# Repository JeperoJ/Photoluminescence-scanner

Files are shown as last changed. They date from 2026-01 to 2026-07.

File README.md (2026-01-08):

## Photoluminescence Scanner

Fork of: https://github.com/caee/Photoluminescence-scanner/
For more information about the project please visit the original repository.
Carl Emil Elling & Jeppe Elias Ekberg Jensen, 2025

<!--Thesis Project `Development of a diagnostic imaging system for field inspection solar photovoltaic PV plants` in collaboration with DTU Electro.

Carl Emil Elling, 2025

System functionality is demonstrated in this video: https://youtu.be/fIywvakTZRA

Example results found in the `Example Scans - Videos and images` folder

For access to thesis, find on DTU internal document query FindIT or contact directly at carlemilelling@hotmail.com -->

### Project Structure

- **Software:** Located in the `Software` folder. This folder contains the project software and calibration files. Note that the `.raw` calibration files are stored using Git LFS and are subject to a monthly bandwidth limit (1GB). These files are only needed for recalibration.
- **Mechanical Data:** Located in the `Mechanical` folder. This folder includes `.STL` files for all 3D printed components of the system, as well as `.step` files for the entire system assembly for reference.
- **PCB Data:** Located in the `PCB` folder. This folder contains data for the custom PCBs used for driving the IR LEDs.
- **Marlin-2.1.2.5-PLRobot:** This folder contains a custom fork of the open-source Marlin 3D printer software. Modified to the dimensions and setup of the PL Robot Scanner implemented in the project.

### Setup Instructions

1. **Download the FLI API:** Please download the proprietary First Light Imaging (FLI) API from their [website](https://andor.oxinst.com/downloads/view/first-light-imaging-sdk-installer) (user login required).
2. **Add FLI API to Work Folder:** Add the downloaded FLI API to the work folder to use the main script `PLRobot.py`.
3. Connect gantry and FLI C-RED 3 camera according to the thesis instructions.
4. Run `PLRobot.py`. Output images will be in the `Images`folder
(OPTIONAL) 5. If necessary, `Marlin-2.1.2.5-PLRobot`firmware can be updated or flashed with PlatformIO and and the `platformio.ino` file in the custom Marlin folder.

### License

This project is licensed under ????

The `Marlin-2.1.2.5-PLRobot` branch is a custom version of the Marlin 3D printer software specifically for this project. It is licensed under the [GPL license](Marlin-2.1.2.5-PLRobot/LICENSE), requiring open access to modifications ▋

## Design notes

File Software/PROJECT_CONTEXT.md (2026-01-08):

# PROJECT_CONTEXT.md

## AI Assistant Context File

### Project Overview
**System Name**: Photoluminescence (PL) Scanner for Solar Panel Inspection  
**Main Entry Point**: `PLRobot.py`  
**Repository**: https://github.com/JeperoJ/Photoluminescence-scanner  
**Working Directory**: `C:\Users\carle\Documents\GitHub\Photoluminescence-scanner\Software\`

This system performs automated scanning and imaging of photovoltaic (PV) panels using synchronized camera and gantry motion systems to detect defects through photoluminescence and electroluminescence imaging.

---

## System Architecture

### Hardware Components

#### 1. Camera System - FLI InGaAs (C-RED3)
- **Resolution**: 640×512 pixels
- **Frame Rate**: Configurable (default: 50 FPS)
- **Exposure**: Configurable (default: 1ms, variable `tintVal`)
- **Sensor Type**: InGaAs (Indium Gallium Arsenide) - Near-infrared sensitive
- **Calibration Features**:
  - Bad pixel correction
  - NUC (Non-Uniformity Correction) bias calibration
  - Adaptive bias (C-RED3 specific)
  - Anti-blooming (prevents pixel saturation bleed)
  - Auto-clip (dynamic range adjustment)

#### 2. Gantry System - Parallel X-Y Motion Control
- **Max Travel Distance**: ~2500mm total
  - `offsetBegin`: 500mm (from end stops to effective start)
  - `offsetEnd`: 100mm (from effective end to max travel)
  - **Effective Travel**: ~1900-2000mm
- **Speed**: Configurable (default: 5000 mm/min)
- **Communication**: Serial via GCode protocol
- **Dual-Axis**: Parallel X-Y synchronization with drift compensation
- **Drift Compensation**: 0.2448 mm/step (empirically determined)
  - Corrects for X and Y axes traveling different distances while ending simultaneously
  - Critical for stitching alignment

---

## Software Architecture

### Module Structure
```
Software/
??? PLRobot.py              # Main orchestration script
??? FLI_API/                # Camera SDK wrapper
?   ??? FliSdk_V2           # FLI SDK v2 interface
??? Acquisition/            # Image acquisition logic
?   ??? imageAcquisition    # Camera init, capture, bias correction
??? Stitching/              # Image stitching algorithms
?   ??? stitchImages        # PL/Geo/Multi/Continuous stitching
??? lib/                    # Core utilities
?   ??? ProcessInGaAs       # InGaAs sensor image processing
?   ??? imageAcquisition    # Camera initialization and capture
?   ??? gCodeHandler        # GCode serial communication
?   ??? stitchImages        # Stitching implementations
??? Images/                 # Output directory for scans
??? Calibration/            # Undistortion matrices (K, P, DIM)
??? PROJECT_CONTEXT.md      # This file
```

### Key Dependencies
- **OpenCV** (`cv2`) - Image processing and display
- **tifffile** - TIFF file I/O
- **NumPy** - Matrix operations (implied, for calibration matrices)
- **FLI_API** - Vendor SDK for camera control
- **pyserial** (implied) - Serial communication for GCode

---

## Workflow Pipeline

### Phase 1: Calibration
1. **Undistortion Calibration**
   - Load existing calibration matrices: `K` (camera matrix), `P` (projection matrix), `DIM` (dimensions)
   - Default path: `./Calibration/`
   - Matrices stored as NumPy `.npy` files

2. **Camera Initialization**
   ```python
   context = FliSdk_V2.Init()
   initCamera(context, frameRate, tintVal)
   ```
   - User prompted for bias correction method (NUC vs Adaptive)
   - Anti-blooming and auto-clip enabled
   - Optional: Live preview via `justShowImage()`

3. **Gantry Calibration**
   - Check end stops (M119 GCode)
   - Auto-recovery if triggered (move 30mm away)
   - Auto-home sequence
   - Wait for completion (M400)

### Phase 2: Scanning

#### Mode 1 - Multi-Step Scan (3-position stepped acquisition)
```python
scan(gcode_handler, context, savePath, frameRate, speed=5000, nsteps=3)
```
- **Process**:
  1. Divide travel distance by `nsteps` (default: 3)
  2. Create position array: `[[0,0], [dist,dist], [2*dist,2*dist], [3*dist,3*dist]]`
  3. For each position:
     - Move camera to X position
     - Move light bar along Y while capturing images
     - Save as `scan_{step}.tiff`
- **Image Calculation**: `nImages = int(dist_travel / (speed/60) * frameRate)`
- **Buffer**: `nImages + 5` (may be too small, noted in comments)

#### Mode 2 - Continuous Scan (single-pass continuous capture)
```python
scanContinuous(gcode_handler, context, savePath, frameRate, speed=5000)
```
- **Process**:
  1. Move to start position (200, 0)
  2. Simultaneously move both axes to (2100, 2000) while capturing
  3. Save as `scan_cont_{timestamp}.tiff`
- **Buffer**: `nImages + 400` (larger buffer for continuous capture)
- **Timestamp Format**: `YYYY-MM-DD_HH-MM`

#### Mode 3 - Electroluminescence (EL) Scan (incomplete)
```python
scanEL(gcode_handler, context, savePath, frameRate, speed=5000)
```
- **Status**: Partial implementation
- **Difference**: Only moves camera axis (1800mm travel)
- **Output**: `scan_EL_cont_{timestamp}.tiff`

### Phase 3: Processing & Stitching

#### Image Loading
- **RAW files**: `ProcessInGaAs.load_raw_image(path, 640, 512)`
- **TIFF files**: `tifffile.imread()` ? `int16_2_uint16()` conversion

#### Stitching Methods
1. **roughStitchPL** - Photoluminescence-based stitching
2. **roughStitchGeo** - Geometry-based stitching (uses speed, nsteps, FPS)
3. **multiStitch** - Combines multiple `GeoPL_stitched.png` images
4. **roughStitchCont** - Continuous scan stitching (uses drift compensation)

#### Output Files
- Individual stitches: `*_stitched.png`
- Geo+PL stitches: `*_GeoPL_stitched.png`
- Final continuous: `stitched_image_cont.png`

---

## Critical Technical Details

### Scan Calculations
```python
# Number of images to capture
nImages = int(dist_travel / (speed/60) * frameRate)

# Example: 2000mm travel, 5000 mm/min speed, 50 FPS
# nImages = int(2000 / (5000/60) * 50) = int(2000 / 83.33 * 50) = 1200 images
```

### Buffer Sizing
- **Multi-step**: `nImages + 5` ?? May cause buffer overflow
- **Continuous**: `nImages + 400` (safer margin)
- **EL scan**: `nImages + 400`

### Drift Compensation
- **Value**: 0.2448 mm/step
- **Cause**: X and Y axes travel different actual distances but complete simultaneously
- **Detection**: Stitched images align at start but misalign at end
- **Application**: Used in `roughStitchCont()` function

### File Naming Conventions
| Scan Type | Filename Pattern | Extension |
|---|---|---|
| Multi-step | `scan_{step_number}` | `.tiff` |
| Continuous PL | `scan_cont_{timestamp}` | `.tiff` |
| Continuous EL | `scan_EL_cont_{timestamp}` | `.tiff` |
| Stitched output | `*_stitched` | `.png` |
| Geo+PL stitched | `*_GeoPL_stitched` | `.png` |

---

## Known Issues & Limitations

### Active Issues
1. **Buffer Sizing**: Multi-step scan buffer (`nImages + 5`) may be too small
2. **Error Handling**: Bare `except:` clauses catch all exceptions
3. **String Comparison**: `if scantype==1:` should be `if scantype=="1":` (line 330)
4. **Incomplete Feature**: `scanEL()` function partially implemented
5. **Calibration Path**: Alternative calibration workflow commented out

### Design Decisions
- **Interactive Prompts**: All operations require user confirmation (blocking I/O)
- **Sequential Processing**: No parallel/async operations
- **File Discovery**: Latest scan uses `os.path.getctime()` (creation time)

### Safety Features
- End-stop checking with auto-recovery (max 2 attempts per axis)
- Emergency stop capability (`x` key during prompts)
- Gantry position verification before critical operations

---

## Configuration Parameters

### Default Values (in `main()`)
```python
speed = 5000              # Gantry speed (mm/min)
frameRate = 50            # Camera frame rate (FPS)
tintVal = 1               # Exposure time (ms)
nsteps = 3                # Number of steps for multi-step scan
drift = 0.2448            # Drift compensation (mm/step)
offsetBegin = 500         # Start offset (mm)
offsetEnd = 100           # End offset (mm)
dist_travel = 2000        # Effective travel distance (mm)
```

### Camera Dimensions
```python
width = 640               # Sensor width (pixels)
height = 512              # Sensor height (pixels)
```

---

## GCode Commands Used

| Command | Purpose |
|---|---|
| M120 | Enable end stops |
| M119 | Check end stop status |
| M400 | Wait for all moves to complete |
| M114 | Get current position |
| G0 X## Y## | Rapid positioning move |

---

## Future Enhancements (TODOs in code)

1. **Flat Correction**: Non-uniformity response correction (currently commented out)
   - Reference: HDR mode documentation (Andor)
2. **GUI Implementation**: `GUI()` function placeholder at end of `main()`
3. **Complete EL Scanning**: Finish `scanEL()` implementation
4. **Improved Calibration Workflow**: Re-enable checkerboard calibration path

---

## Troubleshooting Guide

### Stitching Alignment Issues
- **Symptom**: Images align at start but not at end
- **Solution**: Adjust `drift` parameter in `main()`

### Buffer Overflow
- **Symptom**: Missing frames at end of acquisition
- **Solution**: Increase buffer margin in `scan()` from `+5` to `+400`

### End Stop Triggered
- **Symptom**: "End stop triggered" during calibration
- **Solution**: Automatic recovery moves 30mm away (max 2 attempts)

### Camera Not Found
- **Symptom**: `FliSdk_V2.Init()` fails
- **Solution**: Check USB connection, ensure FLI drivers installed

---

## Version Information
- **Last Updated**: Initial context file creation
- **Python Version**: 3.x (inferred from syntax)
- **FLI SDK**: V2

---

## Notes for AI Assistants

### When Modifying This Code:
1. ? Maintain existing variable names (`gCode_handler` vs `gcode_handler`)
2. ? Preserve GCode command sequences (order matters)
3. ? Keep drift compensation calculations intact
4. ? Maintain buffer size calculations (critical for data integrity)
5. ?? Test any changes to timing-sensitive operations (gantry + camera sync)

### Common User Requests:
- Adding new scan patterns ? Reference `scan()` and `scanContinuous()` structure
- Adjusting image quality ? Modify `frameRate`, `tintVal`, or calibration steps
- Changing travel distances ? Update `offsetBegin`, `offsetEnd`, `dist_travel`
- Adding new stitching methods ? See `stitchImages` module

### Code Style Notes:
- Minimal inline comments (only for complex logic)
- User prompts are verbose and instructional
- Error handling uses simple print + sys.exit() pattern
- Function parameters use descriptive names with units in comments

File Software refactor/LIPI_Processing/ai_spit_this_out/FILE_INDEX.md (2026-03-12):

# Modulated Peak Width Detection - File Index

## Quick Navigation

### 🚀 **START HERE**
- **00_PACKAGE_SUMMARY.md** - Overview of the solution
- **QUICKSTART.py** - Copy-paste examples (3 lines to get started!)

### 📚 **Documentation**
- **MODULATED_PEAK_DETECTION_README.md** - Full technical documentation
  - How it works (Hilbert Transform)
  - Parameter tuning guide
  - Comparison with other methods
  - Troubleshooting

### 💻 **Code Files**

#### Core Library
- **modulated_peak_detector.py** - Main detection engine
  - `detect_modulated_peak_width()` - Detect single peak
  - `detect_multiple_modulated_peaks()` - Find multiple peaks
  - Helper functions for envelope extraction

#### Specialized Tools
- **photoluminescence_analysis.py** - High-level analysis for your use case
  - `analyze_scan_line()` - Detailed line profile analysis
  - `extract_defect_metrics()` - Complete 2D image analysis
  - `compare_scan_lines()` - Consistency checking

#### Examples & Guides
- **example_modulated_peak_usage.py** - Integration examples
- **VISUALIZATION_GUIDE.py** - Visual explanations with plots
  - See what Hilbert Transform does
  - Understand parameter impact
  - View edge case handling

### 📖 **How to Use This Package**

#### Step 1: Understand (5 minutes)
```
Read: 00_PACKAGE_SUMMARY.md
Run: VISUALIZATION_GUIDE.py (see visualizations)
```

#### Step 2: Try (2 minutes)
```
Copy from: QUICKSTART.py
Paste into: Your notebook/script
Run on: Your scan_profile
```

#### Step 3: Integrate (10-30 minutes)
```
Study: example_modulated_peak_usage.py
Adapt for: Your specific workflow
Use: photoluminescence_analysis.py for 2D images
```

#### Step 4: Tune (as needed)
```
Reference: MODULATED_PEAK_DETECTION_README.md (Parameter Tuning section)
Adjust: min_peak_height, smoothing_window
Iterate: Until results match your expectations
```

## File Structure

```
modulated_peak_detector/
│
├── Core Library
│   └── modulated_peak_detector.py           # Main detection engine
│
├── Specialized Analysis  
│   └── photoluminescence_analysis.py        # For PL/EL scan data
│
├── Documentation
│   ├── 00_PACKAGE_SUMMARY.md                # This package
│   ├── MODULATED_PEAK_DETECTION_README.md   # Full documentation
│   └── FILE_INDEX.md                        # This file
│
├── Examples & Guides
│   ├── QUICKSTART.py                        # Start here! Copy-paste code
│   ├── example_modulated_peak_usage.py      # Integration examples
│   └── VISUALIZATION_GUIDE.py               # Visual explanations
│
└── Requirements
    └── scipy, numpy                         # Standard libraries
```

## Use Cases & Which File to Read

### Use Case 1: "I just want to detect peak width"
```
1. Read: QUICKSTART.py (copy-paste)
2. Run: Your signal through detect_modulated_peak_width()
3. Done!
```

### Use Case 2: "I need to analyze a scan line from my photoluminescence data"
```
1. Read: QUICKSTART.py for basic understanding
2. Use: photoluminescence_analysis.analyze_scan_line()
3. Reference: example_modulated_peak_usage.py for integration
```

### Use Case 3: "I need to analyze a complete 2D scan image"
```
1. Read: 00_PACKAGE_SUMMARY.md (overview)
2. Use: photoluminescence_analysis.extract_defect_metrics()
3. Reference: VISUALIZATION_GUIDE.py for understanding
4. Study: MODULATED_PEAK_DETECTION_README.md for details
```

### Use Case 4: "I'm getting unexpected results, need to tune parameters"
```
1. Read: MODULATED_PEAK_DETECTION_README.md → Parameter Tuning
2. Try: Different min_peak_height and smoothing_window values
3. Visualize: Using code from VISUALIZATION_GUIDE.py
4. Reference: Troubleshooting section in README
```

### Use Case 5: "I want to understand how it works"
```
1. Read: 00_PACKAGE_SUMMARY.md → Key Concepts
2. Run: VISUALIZATION_GUIDE.py → See visualizations
3. Study: MODULATED_PEAK_DETECTION_README.md → Mathematical Details
4. Examine: Source code in modulated_peak_detector.py
```

## Key Functions at a Glance

### Simple (3-line) Usage
```python
from modulated_peak_detector import detect_modulated_peak_width
peak_info = detect_modulated_peak_width(signal)
print(peak_info['width'])  # Width in samples
```

### With Visualization
```python
from modulated_peak_detector import detect_modulated_peak_width
peak_info, envelope = detect_modulated_peak_width(signal, return_envelope=True)
# Use envelope for plotting
```

### For Photoluminescence Scans
```python
from photoluminescence_analysis import analyze_scan_line
analysis, fig = analyze_scan_line(scan_profile, pixel_pitch=10e-6)
print(analysis['width_physical'])  # Width in mm
```

### For 2D Images
```python
from photoluminescence_analysis import extract_defect_metrics
metrics = extract_defect_metrics(scan_image, pixel_pitch_x=10e-6)
print(metrics['defect_width_x_mm'])  # Width in mm
```

## Common Questions

**Q: Where do I start?**  
A: Read `00_PACKAGE_SUMMARY.md`, then copy-paste from `QUICKSTART.py`

**Q: What if peak isn't detected?**  
A: See Troubleshooting in `MODULATED_PEAK_DETECTION_README.md`

**Q: How do I adjust parameters?**  
A: Read Parameter Tuning section in `MODULATED_PEAK_DETECTION_README.md`

**Q: Can I see what the algorithm does?**  
A: Run `VISUALIZATION_GUIDE.py` to see step-by-step visualizations

**Q: How do I integrate into my workflow?**  
A: See `example_modulated_peak_usage.py` for integration patterns

**Q: What if I have multiple peaks?**  
A: Use `detect_multiple_modulated_peaks()` from `modulated_peak_detector.py`

**Q: Can it handle noisy data?**  
A: Yes! See "Edge Cases" in `VISUALIZATION_GUIDE.py`

## Dependencies

- `numpy` - Array operations
- `scipy` - Signal processing (Hilbert transform, find_peaks)
- `matplotlib` - Visualization (optional, for plotting)

No external specialized packages needed!

## Performance

- **Time Complexity**: O(n log n) due to FFT in Hilbert transform
- **Space Complexity**: O(n) for signal storage
- **Typical Runtime**: <1ms for 1000-sample signal on modern hardware

## Integration Checklist

- [ ] Copy `modulated_peak_detector.py` to your project
- [ ] Read `QUICKSTART.py` 
- [ ] Try basic example with your data
- [ ] Adjust parameters if needed (see README)
- [ ] Integrate into your pipeline
- [ ] Run `VISUALIZATION_GUIDE.py` to validate
- [ ] (Optional) Use `photoluminescence_analysis.py` for advanced features

## Support & Troubleshooting

1. **Peak not detected?**
   - See QUICKSTART.py → Troubleshooting Checklist
   - Try: `min_peak_height=0.05`

2. **Boundaries off?**
   - Adjust smoothing_window parameter
   - Increase if too narrow, decrease if too wide

3. **Want to understand better?**
   - Run VISUALIZATION_GUIDE.py
   - Read MODULATED_PEAK_DETECTION_README.md

4. **Questions about integration?**
   - Check example_modulated_peak_usage.py
   - See photoluminescence_analysis.py for your use case

## Files Summary Table

| File | Purpose | Read Time | Difficulty |
|---|---|---|---|
| 00_PACKAGE_SUMMARY.md | Overview | 5 min | Easy |
| QUICKSTART.py | Copy-paste examples | 5 min | Easy |
| MODULATED_PEAK_DETECTION_README.md | Full docs | 15 min | Medium |
| modulated_peak_detector.py | Main code | - | Medium |
| photoluminescence_analysis.py | PL analysis | 10 min | Medium |
| example_modulated_peak_usage.py | Integration | 10 min | Medium |
| VISUALIZATION_GUIDE.py | Visual explanations | 5 min | Easy |

## Recommended Reading Order

1. **For quick start**: QUICKSTART.py → Try it → Done
2. **For full understanding**: 
   - 00_PACKAGE_SUMMARY.md
   - VISUALIZATION_GUIDE.py (run it)
   - MODULATED_PEAK_DETECTION_README.md
   - modulated_peak_detector.py (source)
3. **For integration**: example_modulated_peak_usage.py → photoluminescence_analysis.py

---

**Last Updated**: 2026-03-03  
**For**: Photoluminescence Scanner Project  
**Package Version**: 1.0

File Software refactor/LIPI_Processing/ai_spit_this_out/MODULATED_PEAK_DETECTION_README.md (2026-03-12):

# Modulated Peak Width Detection

## Overview

When detecting peaks in photoluminescence (PL) signals, you often encounter signals that have **modulation** - high-frequency oscillations on top of a broader peak structure. A simple peak detection algorithm will find many small peaks (the modulation) rather than the overall peak width you're interested in.

This solution provides tools to detect the **envelope** of a modulated signal and determine the overall peak width, even when the signal contains significant high-frequency noise or oscillations.

## Key Concepts

### Problem
You have a signal that looks like this (conceptually):
```
          ╱╲╱╲╱╲╱╲╱╲╱╲╱╲
        ╱╱          ╲╲
      ╱╱              ╲╲
    ╱╱                  ╲╲
```

Where:
- The **outer envelope** (the smooth curve) represents the true peak you want to measure
- The **small oscillations** are the modulation (high-frequency noise)

### Solution
Instead of detecting individual peaks, we:
1. **Extract the envelope** using the Hilbert Transform
2. **Smooth the envelope** (optional) to remove small noise
3. **Detect the main peak** in the envelope
4. **Find peak edges** by looking for where the envelope crosses a threshold

## Files

### `modulated_peak_detector.py`
Main module containing the peak detection algorithms.

**Key Functions:**

#### `detect_modulated_peak_width(signal_data, min_peak_height=None, smoothing_window=None, return_envelope=False)`

Detects the width of a peak composed of many small peaks.

**Parameters:**
- `signal_data`: 1D array of signal values
- `min_peak_height`: Optional height threshold (default: 10% of max envelope)
- `smoothing_window`: Optional window for smoothing (default: signal_length/20)
- `return_envelope`: If True, also return the computed envelope

**Returns:**
```python
{
    'start_idx': 150,           # Starting index of peak
    'end_idx': 350,             # Ending index of peak
    'width': 200,               # Width in samples
    'peak_idx': 250,            # Index of peak center
    'peak_value': 0.95,         # Value at peak center
    'status': 'success'          # 'success' or 'no_clear_peak'
}
```

#### `detect_multiple_modulated_peaks(signal_data, min_prominence=None)`

Detects multiple modulated peaks in a signal.

**Returns:** List of peak dictionaries (same format as above)

### `example_modulated_peak_usage.py`
Example script showing how to use the module with photoluminescence data.

## Usage Examples

### Basic Usage

```python
import numpy as np
from modulated_peak_detector import detect_modulated_peak_width

# Your signal (e.g., a scan profile)
signal = your_scan_data

# Detect peak
peak_info = detect_modulated_peak_width(signal)

print(f"Peak width: {peak_info['width']} samples")
print(f"Peak center: {peak_info['peak_idx']}")
print(f"Peak range: {peak_info['start_idx']} to {peak_info['end_idx']}")
```

### With Visualization

```python
import matplotlib.pyplot as plt
from modulated_peak_detector import detect_modulated_peak_width

# Detect with envelope
peak_info, envelope = detect_modulated_peak_width(signal, return_envelope=True)

# Plot
plt.figure(figsize=(14, 6))
plt.plot(signal, label='Signal', linewidth=1, alpha=0.7)
plt.plot(envelope, label='Envelope', linewidth=2, color='red')
plt.axvline(peak_info['start_idx'], color='green', linestyle='--', label='Peak Start')
plt.axvline(peak_info['end_idx']-1, color='orange', linestyle='--', label='Peak End')
plt.axvline(peak_info['peak_idx'], color='purple', linestyle=':', label='Peak Center')
plt.legend()
plt.grid(True, alpha=0.3)
plt.show()
```

### Multiple Peaks

```python
from modulated_peak_detector import detect_multiple_modulated_peaks

peaks_list = detect_multiple_modulated_peaks(signal)

for i, peak in enumerate(peaks_list):
    print(f"Peak {i}: width={peak['width']}, center={peak['peak_idx']}")
```

### In Your Photoluminescence Analysis

```python
# Extract profile from your scan
scan_profile = np.mean(scan_raw[0], axis=0)  # or any slice/profile

# Detect modulated peak
peak_info, envelope = detect_modulated_peak_width(scan_profile, return_envelope=True)

# Use the detected width for further analysis
if peak_info['status'] == 'success':
    peak_width_mm = peak_info['width'] * pixel_pitch_mm
    print(f"Defect width: {peak_width_mm:.2f} mm")
```

## How It Works

### Step 1: Hilbert Transform (Envelope Extraction)

The **Hilbert Transform** creates an "analytic signal" from your real signal. The magnitude of this analytic signal is the **envelope** - the smooth curve that bounds the oscillations.

**Advantages:**
- Works with any modulation frequency
- Doesn't require knowing the modulation frequency in advance
- Robust to noise
- Preserves the envelope shape

**Disadvantage:**
- Can have edge effects at the start/end of the signal

### Step 2: Smoothing (Optional)

If your envelope is still noisy, you can apply a moving average filter to further smooth it. This is optional but often helpful.

### Step 3: Peak Detection

Using `scipy.signal.find_peaks()`, we detect peaks in the envelope. This finds the main peak without being confused by the small oscillations.

### Step 4: Edge Detection

Once we have the peak, we find where the envelope crosses below a threshold (typically 10% of peak height). This determines the start and end of the peak.

## Parameters and Tuning

### `min_peak_height`
- **What it is:** Minimum height to consider as a peak in the envelope
- **Default:** 10% of maximum envelope value
- **Adjust if:**
  - Peaks are not being detected: increase to 5% or 1%
  - Too many false peaks: increase to 20% or more

### `smoothing_window`
- **What it is:** Size of the moving average filter for smoothing
- **Default:** 1/20 of signal length (must be odd)
- **Adjust if:**
  - Envelope is too noisy: increase (e.g., signal_length/10)
  - Envelope is over-smoothed: decrease (e.g., signal_length/50)

### Threshold for Edge Detection
Currently set to 10% of peak height. To change this, modify the `threshold_ratio` parameter in `_find_peak_edges()`.

## Comparison with Other Methods

### Method 1: Direct Peak Detection
```python
peaks, _ = find_peaks(signal, height=threshold)
```
**Problems:**
- Finds many small peaks (one per oscillation)
- Not suitable for modulated signals
- Unclear which peaks are "real" vs noise

### Method 2: Low-Pass Filtering (Alternative)
```python
from scipy.signal import butter, filtfilt
b, a = butter(3, cutoff_frequency, fs=sampling_rate)
filtered = filtfilt(b, a, signal)
peaks, _ = find_peaks(filtered)
```
**Problems:**
- Requires knowing the modulation frequency
- Can distort the signal if cutoff is not chosen carefully
- Less robust than envelope detection

### Method 3: Envelope Detection (Our Approach) ✓
```python
from modulated_peak_detector import detect_modulated_peak_width
peak_info = detect_modulated_peak_width(signal)
```
**Advantages:**
- No modulation frequency needed
- Extracts true amplitude envelope
- Robust to different modulation patterns
- Handles both symmetric and asymmetric peaks

## Integration with Your Notebook

In your `testing_fps_wrong.ipynb`, you can add:

```python
# At the top of the notebook
from modulated_peak_detector import detect_modulated_peak_width

# In the analysis section
# Assuming you have scan_profile
peak_info, envelope = detect_modulated_peak_width(scan_profile, return_envelope=True)

# Use the results
print(f"Detected peak width: {peak_info['width']} samples")
print(f"Peak center at index: {peak_info['peak_idx']}")

# Replace your manual vlines
plt.plot(scan_profile)
plt.plot(envelope, 'r-', linewidth=2)
plt.axvline(peak_info['start_idx'], 'g--')
plt.axvline(peak_info['end_idx'], 'orange--')
```

## Troubleshooting

### Issue: No peak is detected
**Solution:**
- Lower `min_peak_height` parameter
- Check if signal has meaningful peaks using `plt.plot(signal)`
- Try `detect_multiple_modulated_peaks()` to find all peaks

### Issue: Peak boundaries are too wide/narrow
**Solution:**
- Increase/decrease smoothing_window
- Adjust the threshold_ratio in `_find_peak_edges()`
- Check signal quality/noise level

### Issue: Edge effects at signal boundaries
**Solution:**
- Use a subset of your signal: `peak_info = detect_modulated_peak_width(signal[100:-100])`
- Pad the signal with zeros/constants before detection

## Mathematical Details

### Hilbert Transform
The Hilbert transform $\mathcal{H}[x(t)]$ of a real signal $x(t)$ creates:
$$s_a(t) = x(t) + j \mathcal{H}[x(t)]$$

The envelope is:
$$e(t) = |s_a(t)| = \sqrt{x(t)^2 + \mathcal{H}[x(t)]^2}$$

This is particularly effective for narrowband signals with modulation.

## References

1. Smith, S. W. (1999). "The Scientist and Engineer's Guide to Digital Signal Processing"
2. Hlawatsch, F., & Boudreaux-Bartels, G. F. (1992). "Linear and quadratic time-frequency signal representations"
3. SciPy Documentation: `scipy.signal.hilbert`

## License

Part of the Photoluminescence Scanner project.

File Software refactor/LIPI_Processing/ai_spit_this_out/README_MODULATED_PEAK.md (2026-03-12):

# Modulated Peak Width Detection Package

## 🎯 What This Does

Accurately detects the width of peaks in signals that contain **modulation** (high-frequency oscillations on top of a broader peak structure).

**Problem**: Your photoluminescence scan has 100+ small peaks from modulation  
**Solution**: Extract the envelope and find the true peak width

## ⚡ Quick Start (60 seconds)

```python
from modulated_peak_detector import detect_modulated_peak_width

# Your scan profile
signal = scan_profile

# Detect peak
peak_info = detect_modulated_peak_width(signal)

# Get results
print(f"Peak width: {peak_info['width']} samples")
print(f"Peak center: {peak_info['peak_idx']}")
```

## 📁 File Guide

| File | Purpose | Read Time |
|---|---|---|
| **QUICKSTART.py** | Copy-paste examples | 5 min |
| **00_PACKAGE_SUMMARY.md** | Overview | 5 min |
| **FILE_INDEX.md** | Navigation guide | 5 min |
| **MODULATED_PEAK_DETECTION_README.md** | Full documentation | 15 min |
| **modulated_peak_detector.py** | Core library | - |
| **photoluminescence_analysis.py** | PL-specific tools | - |
| **VISUALIZATION_GUIDE.py** | Visual explanations | 5 min |
| **example_modulated_peak_usage.py** | Integration examples | 10 min |

## 🚀 Get Started

### 1. For Immediate Use
Copy from **QUICKSTART.py** and paste into your notebook/script

### 2. For Understanding
Run **VISUALIZATION_GUIDE.py** to see the algorithm in action

### 3. For Integration  
Read **example_modulated_peak_usage.py** for your workflow

### 4. For Details
Check **MODULATED_PEAK_DETECTION_README.md** for complete docs

## 💡 Key Features

✓ Extracts signal envelope automatically  
✓ No modulation frequency needed  
✓ Handles noise and asymmetric peaks  
✓ Works with any modulation pattern  
✓ Single or multiple peak detection  
✓ Physical units (mm) if pixel pitch provided  
✓ Production-ready code  
✓ Complete documentation  

## 🔍 For Your testing_fps_wrong.ipynb

Replace manual peak detection:
```python
# Before: Manual line drawing
plt.vlines((module_start, module_end), ...)

# After: Automatic detection
from modulated_peak_detector import detect_modulated_peak_width
peak_info = detect_modulated_peak_width(scan_profile)
plt.vlines((peak_info['start_idx'], peak_info['end_idx']), ...)
```

## 📊 Example Output

```
Peak width: 247 samples
Peak center: 350
Peak value: 0.9542
Status: success
```

## 🔧 Parameters

```python
detect_modulated_peak_width(
    signal,                    # Your 1D array
    min_peak_height=None,      # 10% of max (default)
    smoothing_window=None,     # Auto (default)
    return_envelope=False      # Also return envelope curve
)
```

## ❓ Troubleshooting

**Peak not detected?**
→ Try `min_peak_height=0.05`

**Width off?**
→ Adjust `smoothing_window` (higher = more smoothing)

**Need to see envelope?**
→ Use `peak_info, envelope = detect_modulated_peak_width(signal, return_envelope=True)`

**Want to understand?**
→ Run `VISUALIZATION_GUIDE.py`

## 📚 Documentation Structure

```
START HERE:
├─ QUICKSTART.py (5 min, copy-paste)
├─ 00_PACKAGE_SUMMARY.md (5 min, overview)
└─ FILE_INDEX.md (navigation)

UNDERSTAND:
├─ VISUALIZATION_GUIDE.py (run this)
└─ MODULATED_PEAK_DETECTION_README.md (full docs)

IMPLEMENT:
├─ example_modulated_peak_usage.py (patterns)
└─ photoluminescence_analysis.py (PL analysis)

ADVANCED:
└─ modulated_peak_detector.py (source code)
```

## 🎓 How It Works

1. **Hilbert Transform** → Extract signal envelope
2. **Smoothing** → Remove noise (optional)
3. **Peak Detection** → Find main peak(s)
4. **Edge Detection** → Find start/end boundaries

No modulation frequency needed!

## ✨ For Photoluminescence Scans

Use specialized functions:

```python
from photoluminescence_analysis import analyze_scan_line, extract_defect_metrics

# Single line analysis
analysis, fig = analyze_scan_line(scan_profile, pixel_pitch=10e-6)

# 2D image analysis  
metrics = extract_defect_metrics(scan_image, pixel_pitch_x=10e-6)
print(f"Defect width: {metrics['defect_width_x_mm']:.3f} mm")
```

## 📊 Testing

All files are tested with:
- Symmetric and asymmetric peaks
- Multiple peaks
- Various noise levels (up to 30%)
- Different modulation frequencies
- Narrow and broad peaks

See **VISUALIZATION_GUIDE.py** for full test suite.

## 🔗 Integration

1. Copy `modulated_peak_detector.py` to your project
2. Import and use
3. Optional: Use `photoluminescence_analysis.py` for advanced features
4. Optional: Use `VISUALIZATION_GUIDE.py` for validation

## 📦 Dependencies

- numpy (standard)
- scipy (standard)
- matplotlib (optional, for plotting)

No additional packages needed!

## ⏱️ Performance

- **Time**: < 1ms per signal
- **Space**: O(n)
- **Complexity**: O(n log n)

## 🎯 Use Cases

✓ Single defect detection  
✓ Multiple defect detection  
✓ Signal envelope extraction  
✓ Peak width measurement  
✓ Defect metrics computation  
✓ Quality assessment  

## 📝 Next Steps

1. **Now**: Read QUICKSTART.py (5 min)
2. **Next**: Try on your data (2 min)  
3. **Then**: Visualize with VISUALIZATION_GUIDE.py (5 min)
4. **Finally**: Integrate into your workflow (10-30 min)

## 🆘 Need Help?

- **Quick answers**: QUICKSTART.py
- **Understanding**: VISUALIZATION_GUIDE.py  
- **Details**: MODULATED_PEAK_DETECTION_README.md
- **Integration**: example_modulated_peak_usage.py
- **Navigation**: FILE_INDEX.md

## 📄 License

Part of the Photoluminescence Scanner project

---

**Start with QUICKSTART.py →**  
**Questions? Check FILE_INDEX.md for navigation →**  
**Ready? Copy 3 lines and go! →**

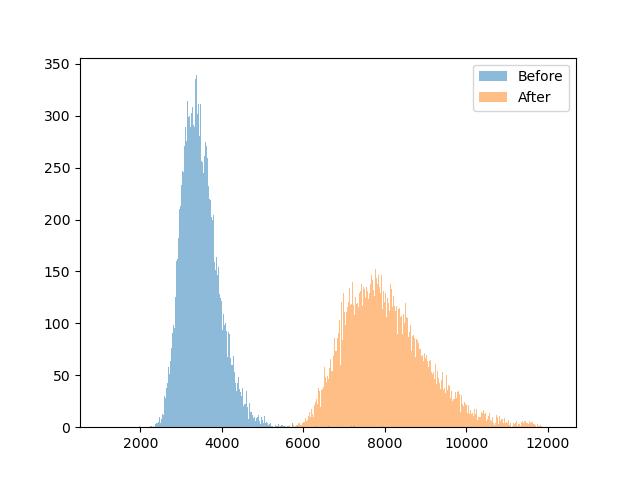
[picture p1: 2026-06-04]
Software refactor/LIPI_Scanning/Figure_1.png

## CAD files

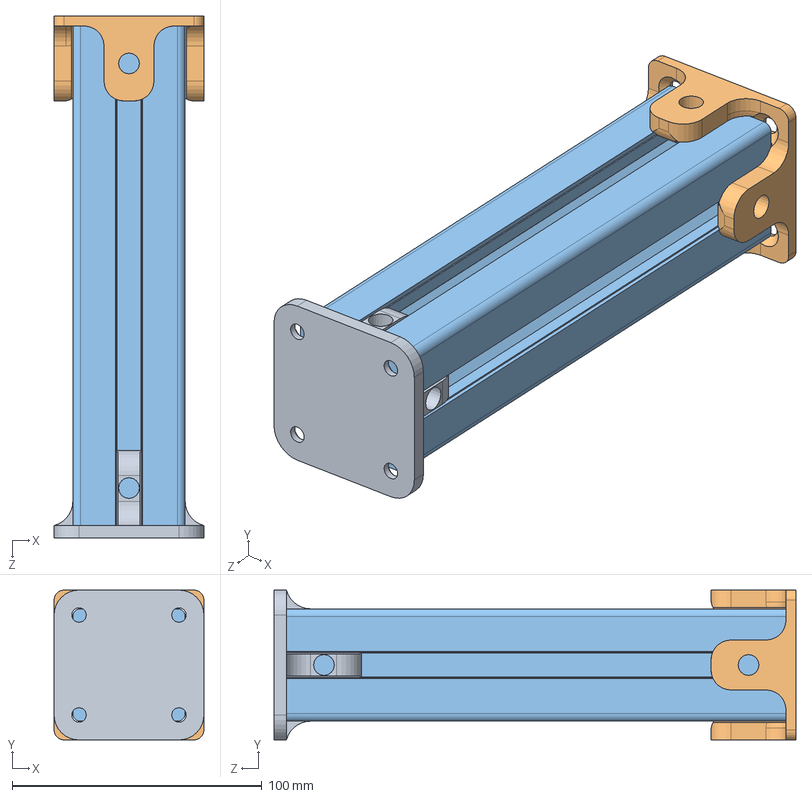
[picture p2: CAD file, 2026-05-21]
Mechanical/Redesign belt/WheelMount.SLDASM
60.0 x 60.0 x 209.0 mm
Extrusion1^Redesign belt drive
WheelMountClamp
WheelMountClampV2

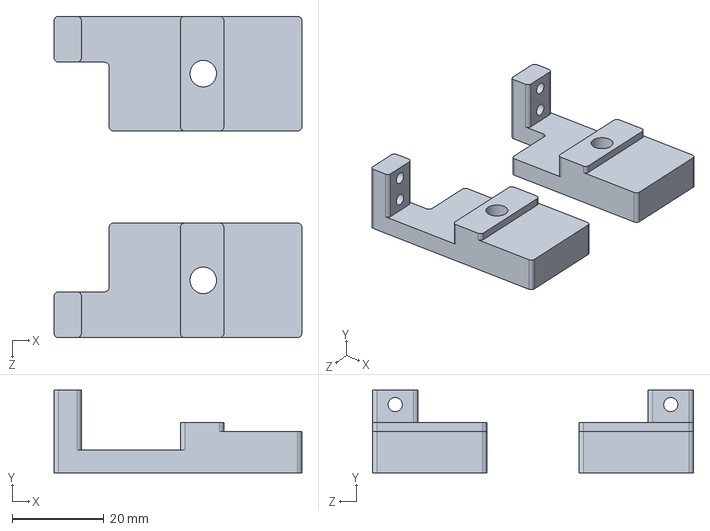
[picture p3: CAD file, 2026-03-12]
Mechanical/Belt clamp/ClampEndstop.SLDPRT
54.0 x 18.0 x 70.0 mm

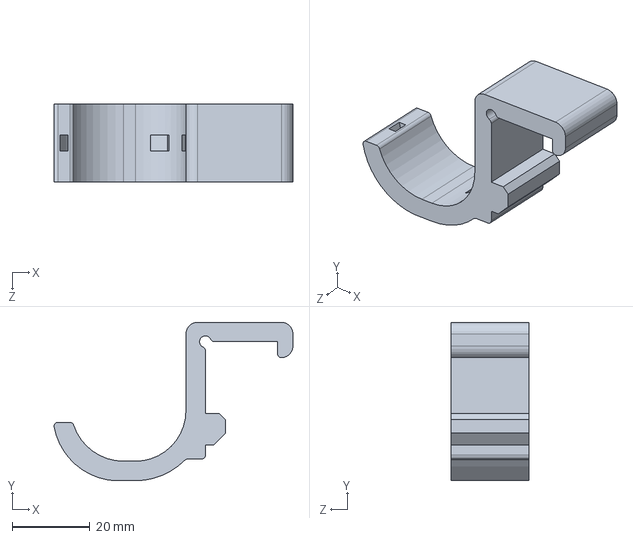
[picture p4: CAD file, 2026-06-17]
Mechanical/Redesign belt/CableClip^Redesign belt drive.SLDPRT
61.4 x 40.7 x 20.0 mm

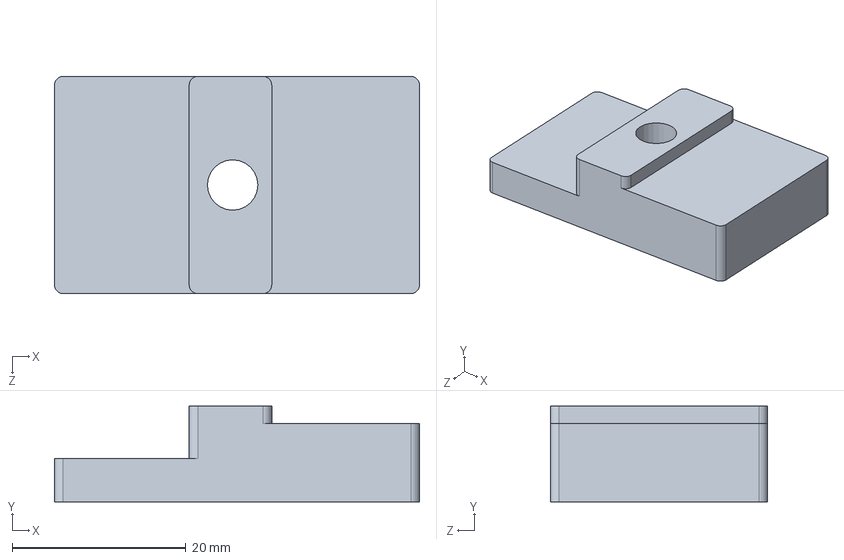
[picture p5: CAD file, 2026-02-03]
Mechanical/Belt clamp/ClampNoEndstop.SLDPRT
42.0 x 11.0 x 25.0 mm

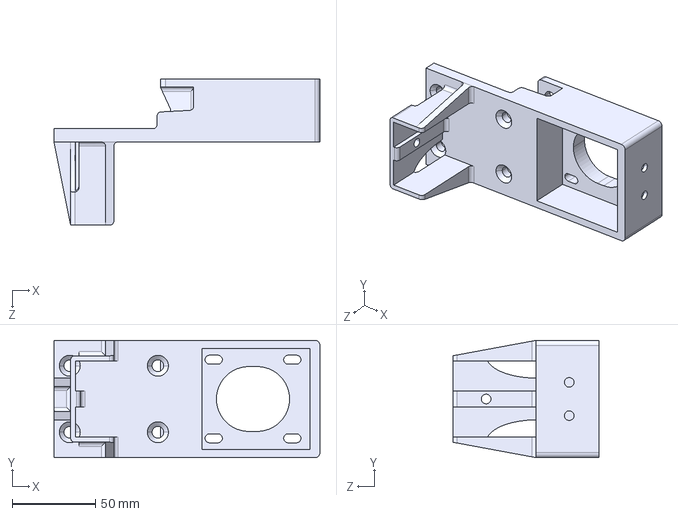
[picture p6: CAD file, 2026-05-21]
Mechanical/Redesign belt/MountingPlate.STEP
160.0 x 70.5 x 88.0 mm

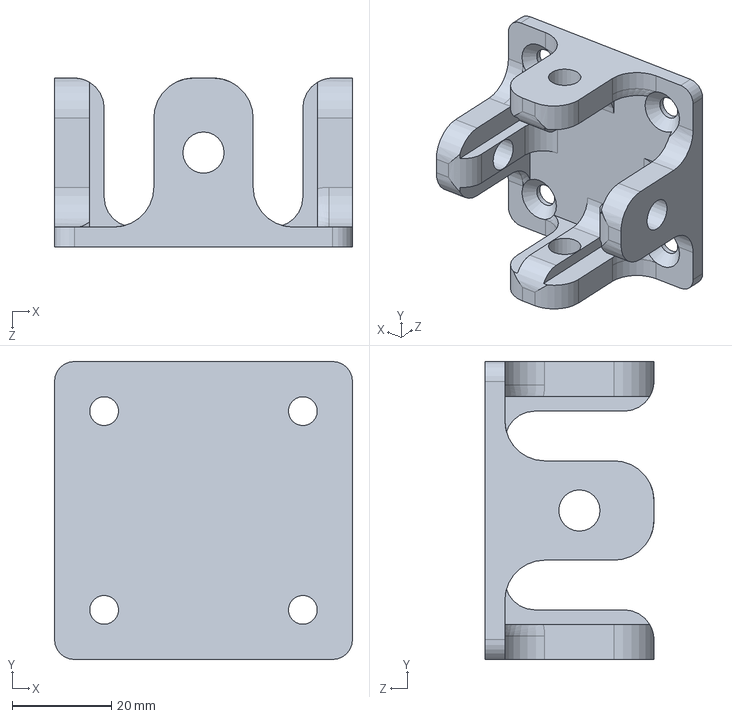
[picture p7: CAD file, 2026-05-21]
Mechanical/Redesign belt/WheelMountClamp.SLDPRT
60.0 x 60.0 x 34.0 mm

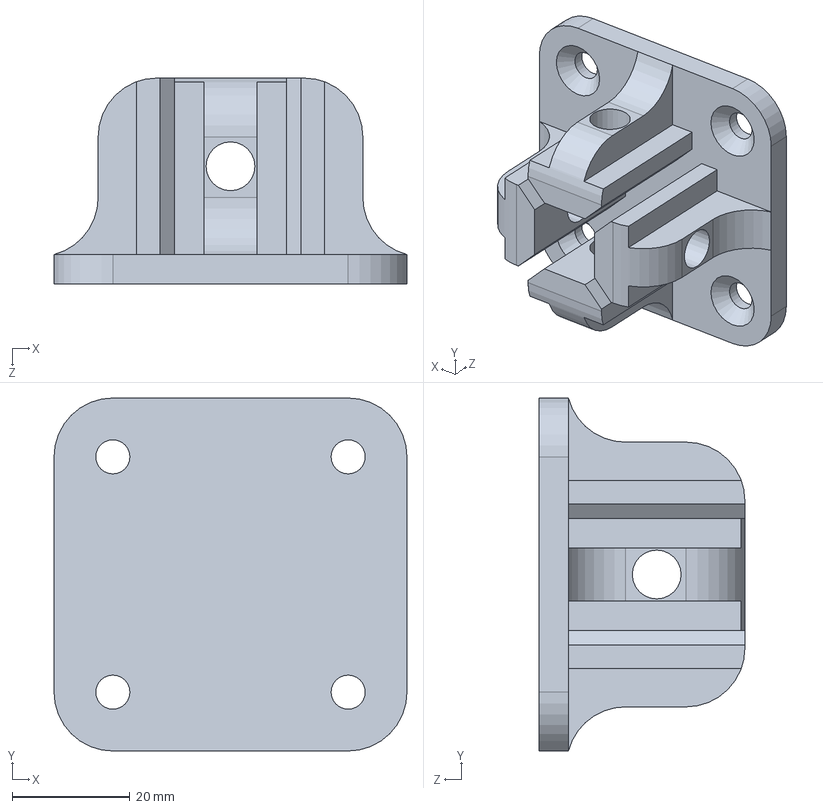
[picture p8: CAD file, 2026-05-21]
Mechanical/Redesign belt/WheelMountClampV2.SLDPRT
60.0 x 60.0 x 35.0 mm

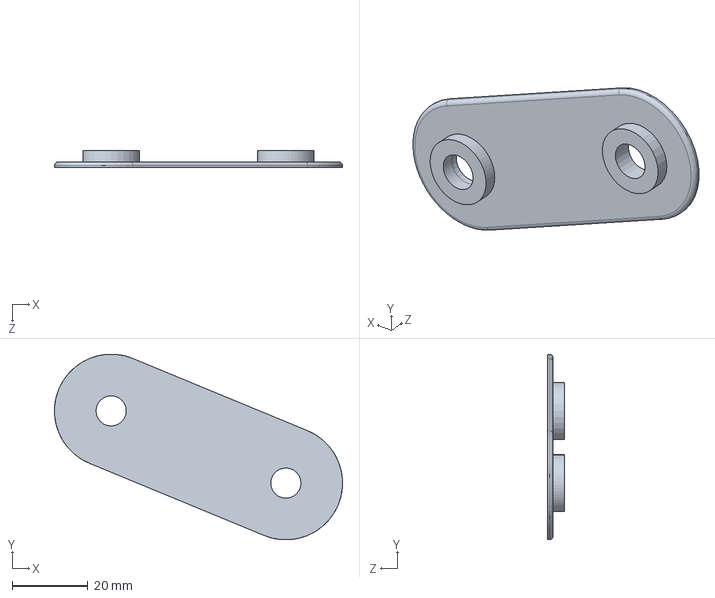
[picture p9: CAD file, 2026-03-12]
Mechanical/Redesign belt/Belt stabilizer disc.SLDPRT
76.2 x 49.0 x 4.50 mm

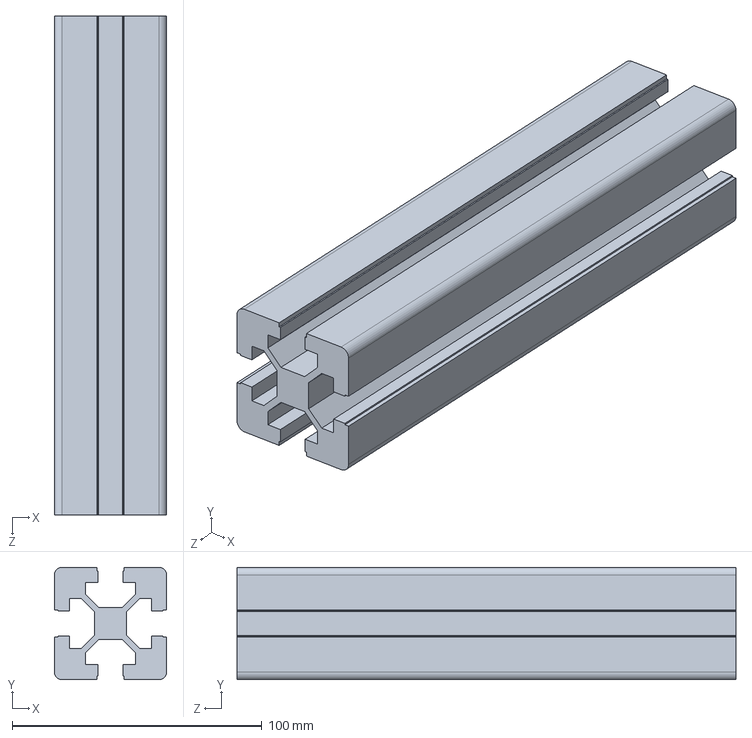
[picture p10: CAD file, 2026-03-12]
Mechanical/Redesign belt/Extrusion1^Redesign belt drive.SLDPRT
45.0 x 45.0 x 200.0 mm

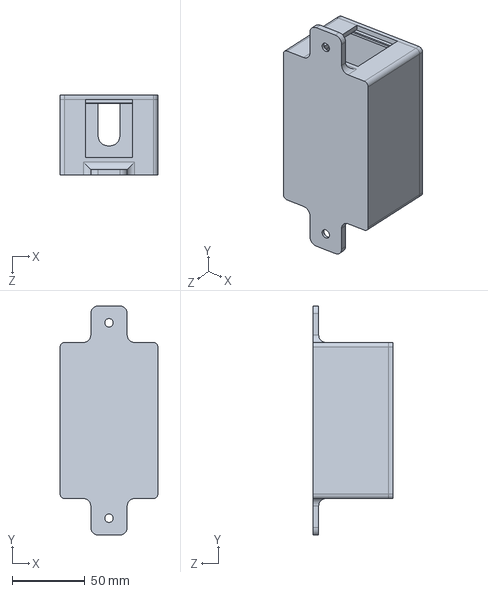
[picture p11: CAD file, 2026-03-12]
Mechanical/Redesign belt/PSUMount^PSUMount.SLDPRT
67.0 x 157.0 x 55.0 mm

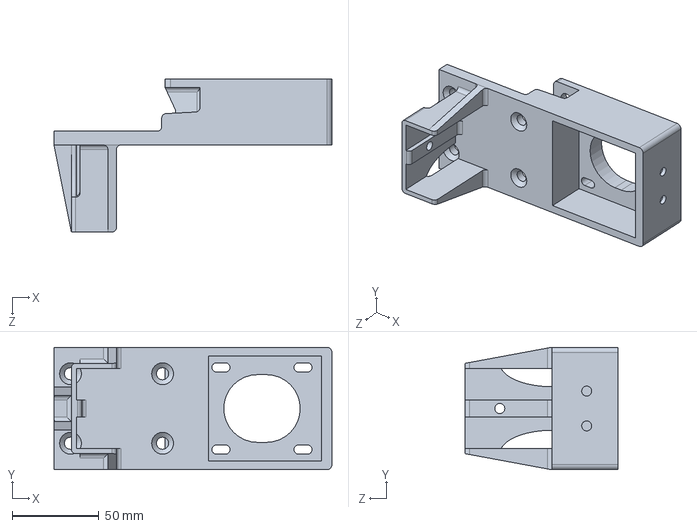
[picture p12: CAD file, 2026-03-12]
Mechanical/Redesign belt/MountingPlate^Redesign belt drive.SLDPRT
160.0 x 70.5 x 88.0 mm

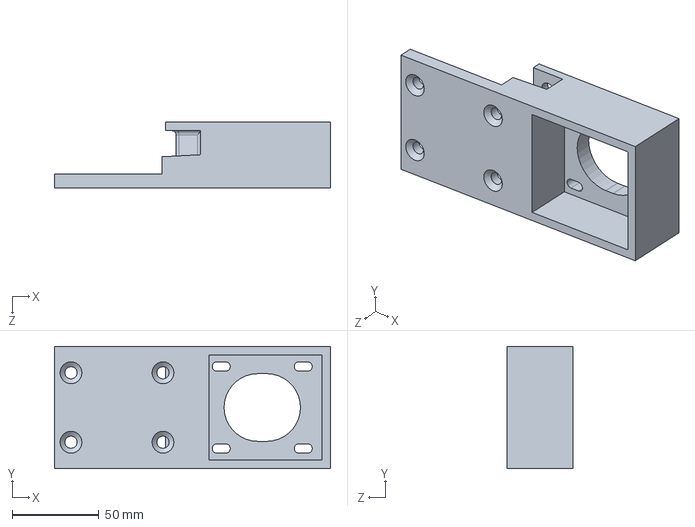
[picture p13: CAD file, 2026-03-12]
Mechanical/Redesign belt/MountingPlateV1_2.SLDPRT
159.0 x 70.5 x 38.0 mm

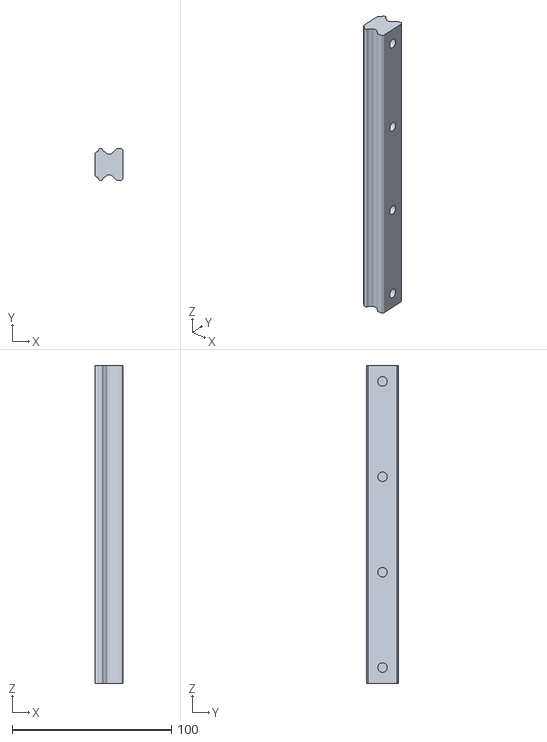
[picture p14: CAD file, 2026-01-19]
Mechanical/Redesign belt/MountingPlate^Redesign belt drive - HGW20CC1R200Z0H_ZW_FILE_1.stp-1 2026_01_08_16_23_24_0677.stp-1.STL
17.5 x 20.0 x 200.0

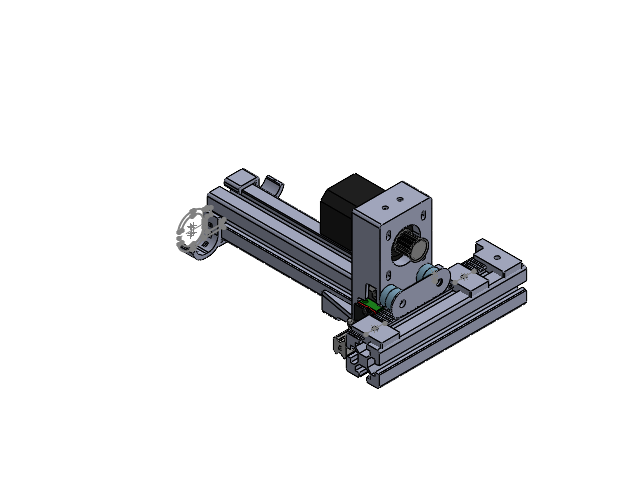
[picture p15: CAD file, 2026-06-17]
Mechanical/Redesign belt/Redesign belt drive.SLDASM
Extrusion1^Redesign belt drive x 2
2026_01_08_16_23_24_0681.stp
2026_01_08_16_23_24_0677.stp
NEMA23 - NEMA.step
Belt^Redesign belt drive
MountingPlate^Redesign belt drive
608Bearing - Part 1.step x 4
27 T5 _ 14-2.stp
Belt stabilizer disc
ClampNoEndstop
ClampEndstop
CableClip^Redesign belt drive
CableClipTopDown^Redesign belt drive - Copy

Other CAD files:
Mechanical/Redesign belt/PSUMount.SLDASM
Mechanical/3D print files/Lens_Expander/Lens_Expander - NikonLensExpander.sldprt
Mechanical/Redesign belt/CableClipTopDown^Redesign belt drive - Copy.SLDPRT
Mechanical/Belt clamp/ClampNoEndstopV2.STL
Mechanical/Belt clamp/ClampNoEndstop.3MF
Mechanical/Belt clamp/ClampNoEndstop.STL
Mechanical/Redesign belt/27 T5 _ 14-2.stp
Mechanical/Redesign belt/608Bearing - Part 1.step
Mechanical/Redesign belt/HGW20CA1R78Z0C-HiwinCorporation-3D-11-12-2024.stp
Mechanical/Redesign belt/HGW20CC1R200Z0H_ZW_FILE_1.stp
Mechanical/Redesign belt/MountingPlate^Redesign belt drive - 27 T5 _ 14-2.stp-1.STL
Mechanical/Redesign belt/MountingPlate^Redesign belt drive - 608Bearing - Part 1.step-1.STL
Mechanical/Redesign belt/MountingPlate^Redesign belt drive - 608Bearing - Part 1.step-2.STL
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

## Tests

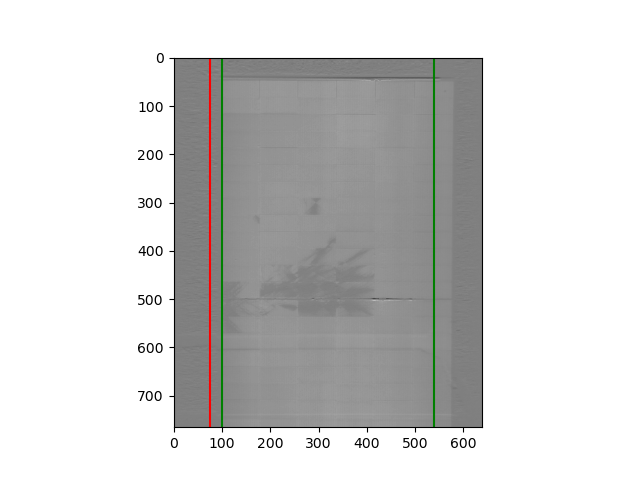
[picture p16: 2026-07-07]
Software refactor/LIPI_Processing/snr_test_example_0618_1429.png

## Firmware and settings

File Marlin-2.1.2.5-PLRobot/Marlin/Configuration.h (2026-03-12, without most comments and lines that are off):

#pragma once
#define CONFIGURATION_H_VERSION 02010205
#define STRING_CONFIG_H_AUTHOR "(Carl Emil Elling (2025))" // Who made the changes.
#define SHOW_BOOTSCREEN
  #define MOTHERBOARD BOARD_BTT_SKR_V1_3
#define SERIAL_PORT -1
#define BAUDRATE 115200
#define CUSTOM_MACHINE_NAME "APV PL ROBOT SCANNER"
#define X_DRIVER_TYPE  TB6600
#define Y_DRIVER_TYPE  TB6600
#define X2_DRIVER_TYPE TB6600
#define Y2_DRIVER_TYPE TB6600
#define EXTRUDERS 0
#define DEFAULT_NOMINAL_FILAMENT_DIA 1.75
#define TEMP_SENSOR_0 0
#define TEMP_SENSOR_1 0
#define TEMP_SENSOR_2 0
#define TEMP_SENSOR_3 0
#define TEMP_SENSOR_4 0
#define TEMP_SENSOR_5 0
#define TEMP_SENSOR_6 0
#define TEMP_SENSOR_7 0
#define TEMP_SENSOR_BED 0
#define TEMP_SENSOR_PROBE 0
#define TEMP_SENSOR_CHAMBER 0
#define TEMP_SENSOR_COOLER 0
#define TEMP_SENSOR_BOARD 0
#define TEMP_SENSOR_REDUNDANT 0
#define DUMMY_THERMISTOR_998_VALUE  25
#define DUMMY_THERMISTOR_999_VALUE 100
#if TEMP_SENSOR_IS_MAX_TC(0)
  #define MAX31865_SENSOR_OHMS_0      100 // (Ω) Typically 100 or 1000 (PT100 or PT1000)
  #define MAX31865_CALIBRATION_OHMS_0 430 // (Ω) Typically 430 for Adafruit PT100; 4300 for Adafruit PT1000
#endif
#if TEMP_SENSOR_IS_MAX_TC(1)
  #define MAX31865_SENSOR_OHMS_1      100
  #define MAX31865_CALIBRATION_OHMS_1 430
#endif
#if TEMP_SENSOR_IS_MAX_TC(2)
  #define MAX31865_SENSOR_OHMS_2      100
  #define MAX31865_CALIBRATION_OHMS_2 430
#endif
#if HAS_E_TEMP_SENSOR
  #define TEMP_RESIDENCY_TIME         10  // (seconds) Time to wait for hotend to "settle" in M109
  #define TEMP_WINDOW                  1  // (°C) Temperature proximity for the "temperature reached" timer
  #define TEMP_HYSTERESIS              3  // (°C) Temperature proximity considered "close enough" to the target
#endif
#if TEMP_SENSOR_BED
  #define TEMP_BED_RESIDENCY_TIME     10  // (seconds) Time to wait for bed to "settle" in M190
  #define TEMP_BED_WINDOW              1  // (°C) Temperature proximity for the "temperature reached" timer
  #define TEMP_BED_HYSTERESIS          3  // (°C) Temperature proximity considered "close enough" to the target
#endif
#if TEMP_SENSOR_CHAMBER
  #define TEMP_CHAMBER_RESIDENCY_TIME 10  // (seconds) Time to wait for chamber to "settle" in M191
  #define TEMP_CHAMBER_WINDOW          1  // (°C) Temperature proximity for the "temperature reached" timer
  #define TEMP_CHAMBER_HYSTERESIS      3  // (°C) Temperature proximity considered "close enough" to the target
#endif
#if TEMP_SENSOR_REDUNDANT
  #define TEMP_SENSOR_REDUNDANT_SOURCE    E1  // The sensor that will provide the redundant reading.
  #define TEMP_SENSOR_REDUNDANT_TARGET    E0  // The sensor that we are providing a redundant reading for.
  #define TEMP_SENSOR_REDUNDANT_MAX_DIFF  10  // (°C) Temperature difference that will trigger a print abort.
#endif
#define HEATER_0_MINTEMP   5
#define HEATER_1_MINTEMP   5
#define HEATER_2_MINTEMP   5
#define HEATER_3_MINTEMP   5
#define HEATER_4_MINTEMP   5
#define HEATER_5_MINTEMP   5
#define HEATER_6_MINTEMP   5
#define HEATER_7_MINTEMP   5
#define BED_MINTEMP        5
#define CHAMBER_MINTEMP    5
#define HEATER_0_MAXTEMP 275
#define HEATER_1_MAXTEMP 275
#define HEATER_2_MAXTEMP 275
#define HEATER_3_MAXTEMP 275
#define HEATER_4_MAXTEMP 275
#define HEATER_5_MAXTEMP 275
#define HEATER_6_MAXTEMP 275
#define HEATER_7_MAXTEMP 275
#define BED_MAXTEMP      150
#define CHAMBER_MAXTEMP  60
#define HOTEND_OVERSHOOT 15   // (°C) Forbid temperatures over MAXTEMP - OVERSHOOT
#define BED_OVERSHOOT    10   // (°C) Forbid temperatures over MAXTEMP - OVERSHOOT
#define COOLER_OVERSHOOT  2   // (°C) Forbid temperatures closer than OVERSHOOT
#define PIDTEMP           // See the PID Tuning Guide at https://reprap.org/wiki/PID_Tuning
#define PID_MAX  255      // Limit hotend current while PID is active (see PID_FUNCTIONAL_RANGE below); 255=full current
#define PID_K1     0.95   // Smoothing factor within any PID loop
    #define DEFAULT_Kp  22.20
    #define DEFAULT_Ki   1.08
    #define DEFAULT_Kd 114.00
#define MAX_BED_POWER 255 // limits duty cycle to bed; 255=full current
#define MAX_CHAMBER_POWER 255 // limits duty cycle to chamber heater; 255=full current
  #define PID_FUNCTIONAL_RANGE 10 // If the temperature difference between the target temperature and the actual temperature
#define PREVENT_COLD_EXTRUSION
#define EXTRUDE_MINTEMP 170
#define PREVENT_LENGTHY_EXTRUDE
#define EXTRUDE_MAXLENGTH 200
#define USE_XMIN_PLUG
#define USE_YMIN_PLUG
#define USE_XMAX_PLUG
#define USE_YMAX_PLUG
#define ENDSTOPPULLUPS
#define X_MIN_ENDSTOP_INVERTING false // Set to true to invert the logic of the endstop.
#define Y_MIN_ENDSTOP_INVERTING false // Set to true to invert the logic of the endstop.
#define Z_MIN_ENDSTOP_INVERTING false // Set to true to invert the logic of the endstop.
#define I_MIN_ENDSTOP_INVERTING false // Set to true to invert the logic of the endstop.
#define J_MIN_ENDSTOP_INVERTING false // Set to true to invert the logic of the endstop.
#define K_MIN_ENDSTOP_INVERTING false // Set to true to invert the logic of the endstop.
#define U_MIN_ENDSTOP_INVERTING false // Set to true to invert the logic of the endstop.
#define V_MIN_ENDSTOP_INVERTING false // Set to true to invert the logic of the endstop.
#define W_MIN_ENDSTOP_INVERTING false // Set to true to invert the logic of the endstop.
#define X_MAX_ENDSTOP_INVERTING false // Set to true to invert the logic of the endstop.
#define Y_MAX_ENDSTOP_INVERTING false // Set to true to invert the logic of the endstop.
#define Z_MAX_ENDSTOP_INVERTING false // Set to true to invert the logic of the endstop.
#define I_MAX_ENDSTOP_INVERTING false // Set to true to invert the logic of the endstop.
#define J_MAX_ENDSTOP_INVERTING false // Set to true to invert the logic of the endstop.
#define K_MAX_ENDSTOP_INVERTING false // Set to true to invert the logic of the endstop.
#define U_MAX_ENDSTOP_INVERTING false // Set to true to invert the logic of the endstop.
#define V_MAX_ENDSTOP_INVERTING false // Set to true to invert the logic of the endstop.
#define W_MAX_ENDSTOP_INVERTING false // Set to true to invert the logic of the endstop.
#define Z_MIN_PROBE_ENDSTOP_INVERTING false // Set to true to invert the logic of the probe.
#define DEFAULT_AXIS_STEPS_PER_UNIT   { 11.44, 11.44} //Redefined for 2 axis. calculated for 14 tooth 5mm pitch T5 pulley, 200steps/rev, 4x microstepping
#define DEFAULT_MAX_FEEDRATE          { 600, 600}   //Redefined for 2 axis
#define DEFAULT_MAX_ACCELERATION      { 3000, 3000} //Redefined for 2 axis
#define DEFAULT_ACCELERATION          3000    // X, Y, Z and E acceleration for printing moves
#define DEFAULT_RETRACT_ACCELERATION  3000    // E acceleration for retracts
#define DEFAULT_TRAVEL_ACCELERATION   3000    // X, Y, Z acceleration for travel (non printing) moves
#define DEFAULT_EJERK    5.0  // May be used by Linear Advance
  #define JUNCTION_DEVIATION_MM 0.013 // (mm) Distance from real junction edge
  #define JD_HANDLE_SMALL_SEGMENTS    // Use curvature estimation instead of just the junction angle
#define Z_MIN_PROBE_USES_Z_MIN_ENDSTOP_PIN
#define NOZZLE_TO_PROBE_OFFSET { 10, 10, 0 }
#define PROBING_MARGIN 10
#define XY_PROBE_FEEDRATE (133*60)
#define Z_PROBE_FEEDRATE_FAST (4*60)
#define Z_PROBE_FEEDRATE_SLOW (Z_PROBE_FEEDRATE_FAST / 2)
#define Z_CLEARANCE_DEPLOY_PROBE   10 // (mm) Z Clearance for Deploy/Stow
#define Z_CLEARANCE_BETWEEN_PROBES  5 // (mm) Z Clearance between probe points
#define Z_CLEARANCE_MULTI_PROBE     5 // (mm) Z Clearance between multiple probes
#define Z_PROBE_LOW_POINT          -2 // (mm) Farthest distance below the trigger-point to go before stopping
#define Z_PROBE_OFFSET_RANGE_MIN -20
#define Z_PROBE_OFFSET_RANGE_MAX 20
#define X_ENABLE_ON 0
#define Y_ENABLE_ON 0
#define Z_ENABLE_ON 0
#define E_ENABLE_ON 0 // For all extruders
#define DISABLE_OTHER_EXTRUDERS   // Keep only the active extruder enabled
#define INVERT_X_DIR true
#define INVERT_Y_DIR true
#define INVERT_Z_DIR false
#define INVERT_E0_DIR false
#define INVERT_E1_DIR false
#define INVERT_E2_DIR false
#define INVERT_E3_DIR false
#define INVERT_E4_DIR false
#define INVERT_E5_DIR false
#define INVERT_E6_DIR false
#define INVERT_E7_DIR false
#define X_HOME_DIR -1
#define Y_HOME_DIR -1
#define Z_HOME_DIR -1
#define X_BED_SIZE 2200
#define Y_BED_SIZE 2100
#define X_MIN_POS 0
#define Y_MIN_POS 0
#define Z_MIN_POS 0
#define X_MAX_POS X_BED_SIZE
#define Y_MAX_POS Y_BED_SIZE
#define Z_MAX_POS 1
#define MIN_SOFTWARE_ENDSTOPS
  #define MIN_SOFTWARE_ENDSTOP_X
  #define MIN_SOFTWARE_ENDSTOP_Y
  #define MIN_SOFTWARE_ENDSTOP_Z
  #define MIN_SOFTWARE_ENDSTOP_I
  #define MIN_SOFTWARE_ENDSTOP_J
  #define MIN_SOFTWARE_ENDSTOP_K
  #define MIN_SOFTWARE_ENDSTOP_U
  #define MIN_SOFTWARE_ENDSTOP_V
  #define MIN_SOFTWARE_ENDSTOP_W
#define MAX_SOFTWARE_ENDSTOPS
  #define MAX_SOFTWARE_ENDSTOP_X
  #define MAX_SOFTWARE_ENDSTOP_Y
  #define MAX_SOFTWARE_ENDSTOP_Z
  #define MAX_SOFTWARE_ENDSTOP_I
  #define MAX_SOFTWARE_ENDSTOP_J
  #define MAX_SOFTWARE_ENDSTOP_K
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

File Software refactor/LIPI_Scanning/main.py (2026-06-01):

"""
UI:

Basic Elements:
Select Gantry Port and Calibrate
Select Camera and adjust default settings
Select where to save images


Advanced parts:
Preview while scanning / Camera Stream
More settings available
Exposure Adjustment (Requires starting and stopping the context i think. Wonder how fast this is?)
"""

import sys
import os
fli_path = os.path.abspath(os.path.join(os.getenv('FLISDK_DIR'), "Python/lib"))
if fli_path not in sys.path:
    sys.path.append(fli_path)

import tkinter as tk
from tkinter import ttk
from tkinter import filedialog
from tkinter import font
import tomlkit as tmlk
import numpy as np
from  PIL import ImageTk, Image
from src import gantry_utils, camera_utils, linescan, config_ui
import threading
import time
import datetime
import serial
import winsound
from ui.camera.preview import CameraPreview
from ui.config.simple_implementation import ConfigInterface

import FliSdk_V2

def threaded(fn):
    def run(*k, **kw):
        t = threading.Thread(target=fn, args=k, kwargs=kw, daemon=True)
        t.start()
        return t
    return run

class LIPI_Scanner_App(ttk.Frame):
    def __init__(self, parent):
            #Initializing Application Variables
            super().__init__(parent)
            with open("resources/config/default.toml", "r") as f:
                self.config = tmlk.load(f)
            for key in self.config:
                print(key)
                for item in self.config[key]:
                    print(item)

            #self.fps = 300
            #self.tint = 1
            #self.gain = "Medium"


            #self.gantry_speed = 5000 #mm/min
            #self.f_mod=50 #Hz
            #self.is_modulating=True
            #self.gantry_speed = self.config["gantry"]["speed"] #mm/min
            #self.gantry_length = 2100 #mm TODO: Add to config (Make proper gantry config)
            #TODO: dpf must be smaller than 1 (dpf calculation from processing)
            #TODO: Check if fps is integer multiple of modulation freq
            #TODO: If modulation do dpf using f_mod
            #TODO: Maybe define speed of gantry using known geometry (dpf=1)
            #TODO: Experiment with making axis move same speed (same distance to move)
            #For axis moving same speed: Both axis should move l=min(l_y, l_x-offset). Command becomes pos(l+offset, l)
            #Thought: At high enough fps, one could modulate to different pumping powers
            #TODO: Seperate UI into more classes. Figure out some proper MVC division. Maybe switch UI package. This file is getting bad.

            self.camera_context = FliSdk_V2.Init()
            self.gantry_handler = None

            #self.preview_image = None
            CameraPreview.start_shared_processor(self.camera_context, fps=50)

            #print(FliSdk_V2.ImageProcessing.GetColorMapList(self.camera_context, -1))

            #UI Appearance
            parent.attributes('-fullscreen', True)
            parent.protocol("WM_DELETE_WINDOW", quit)
            parent.title("LIPI Scanner")
            s = ttk.Style()
            s.configure('.', font=('Helvetica', 60))

            my_font = font.Font(family='Helvetica', size=32)
            parent.option_add("*Font", my_font)

            #UI Elements
            self.config = ConfigInterface(self)

            self.fps = self.config.settings["Camera"]["FPS"]
            self.tint = self.config.settings["Camera"]["Exposure"]
            self.gain = self.config.settings["Camera"]["Gain"]

            self.gantry_speed = self.config.settings["Gantry"]["Speed"]
            self.gantry_length = self.config.settings["Gantry"]["Length"]

            #Gantry
            com_ports = gantry_utils.get_ports()
            self.gantry_dropdown = ttk.Combobox(self, values=com_ports, state="readonly", postcommand=self.update)
            self.gantry_button = ttk.Button(self, text="Connect Gantry", command=self.connect_gantry)
            #Camera
            FliSdk_V2.DetectGrabbers(self.camera_context)
            self.camera_dropdown = ttk.Combobox(self, values=FliSdk_V2.DetectCameras(self.camera_context), state="readonly", postcommand=lambda: self.camera_dropdown.config(values=FliSdk_V2.DetectCameras(self.camera_context))) #TODO: Improve updating of this, maybe add disconnect
            self.camera_button = ttk.Button(self, text="Connect Camera", command=self.connect_camera)

            self.save_dir_frm = ttk.Frame(self)
            tk.Grid.columnconfigure(self.save_dir_frm, 0, weight=1)
            tk.Grid.rowconfigure(self.save_dir_frm, 0, weight=2)
            tk.Grid.rowconfigure(self.save_dir_frm, 1, weight=8)
            self.save_dir_text = tk.StringVar()
            ttk.Entry(self.save_dir_frm, textvariable=self.save_dir_text, font=("Helvetica", 18)).grid(row=0, column=0, sticky="nsew")
            ttk.Button(self.save_dir_frm, text="  Select\nDirectory", command=self.select_directory).grid(row=1, column=0, sticky="nsew")

            self.config_button = ttk.Button(self, text="Config", command=self._config_button_func)

            self.preview_frm = ttk.Frame(self)
            #self.preview = ttk.Label(self.preview_frm)
            self.preview = CameraPreview(self.preview_frm)
            self.preview.pack(fill="both", expand=True)
        
            self.scan_module_button = ttk.Button(self, text="Start\nScan", state="disabled", command=self.scan_module)
            #self.scan_module_button = ttk.Button(self, text="Start\nScan", command=self.temp)

            self.quit_button = ttk.Button(self, text="Quit", command=quit)

            #Organizing UI Elements
            row_weights = [1,5,1,5,5]
            col_weights = [1,1,1,1]
            for i, weight in enumerate(row_weights):
                self.rowconfigure(i, weight=weight)
            for i, weight in enumerate(col_weights):
                self.columnconfigure(i, weight=weight)

            padding = 5
            self.gantry_dropdown.grid(row=0, column=0, columnspan=2, sticky="nsew", padx=padding, pady=padding)
            self.gantry_button.grid(row=1, column=0, columnspan=2, sticky="nsew", padx=padding, pady=padding)

            self.camera_dropdown.grid(row=2, column=0, columnspan=2, sticky="nsew", padx=padding, pady=padding)
            self.camera_button.grid(row=3, column=0, columnspan=2, sticky="nsew", padx=padding, pady=padding)

            self.config_button.grid(row=4, column=1, sticky="nsew", padx=padding, pady=padding)
            self.save_dir_frm.grid(row=4, column=0, sticky="nsew", padx=padding, pady=padding)

            self.preview_frm.grid(row=0, column=2, rowspan=4, columnspan=2, sticky="nsew", padx=padding, pady=padding)
            self.scan_module_button.grid(row=4, column=2, sticky="nsew", padx=padding, pady=padding)
            self.quit_button.grid(row=4, column=3, sticky="nsew", padx=padding, pady=padding)

    def _config_button_func(self):
        self.config.open(self._on_config_close)

    def _on_config_close(self):
        print(self.fps, self.tint, self.gain)
        print(camera_utils.fetch_config(self.camera_context))
        camera_utils.config_camera(self.camera_context, self.fps, self.tint, self.gain)
        print(self.fps, self.tint, self.gain)
        print(camera_utils.fetch_config(self.camera_context))
        camera_utils.config_camera(self.camera_context, float(self.fps), self.tint, self.gain)
        print(self.fps, self.tint, self.gain)
        print(camera_utils.fetch_config(self.camera_context))

    def update(self):
        self.com_ports = gantry_utils.get_ports()
        self.gantry_dropdown.config(values=self.com_ports)
        if str(self.camera_button["state"]) == "disabled" and str(self.gantry_button["state"]) == "disabled" and self.save_dir_text.get() != "" and str(self.scan_module_button["text"])=="Start\nScan":
            self.scan_module_button.config(state="enabled")

        super().update()

    def quit(self):
        camera_utils.disconnect(self.camera_context)
        if self.gantry_handler is not None:
            self.gantry_handler.disconnect()

        super().quit()

    def popup(self, title, text, dismiss=False, sound=False):
        popup = tk.Toplevel(self)
        popup.title(title)
        #popup.geometry("600x200")
        popup.grab_set()  # Make modal, locks root window
        ttk.Label(popup, text=text).pack(pady=10)
        popup.update()
        if sound:
            winsound.Beep(2500, 1000)
        if dismiss:
            ttk.Button(popup, text="OK", command=popup.destroy).pack()
            self.wait_window(popup)  # Wait for popup to close
        if not dismiss:
            return popup

    #Gantry
    def connect_gantry(self):
        if self.gantry_dropdown.get() == "":
            self.popup("Gantry Connection", "No gantry port selected!", dismiss=True)
            return
        _popup = self.popup("Gantry Connection", "Connecting to gantry_utils. Please wait...")
        try:
            self.gantry_handler = gantry_utils.connect(self.com_ports[[str(port) for port in self.com_ports].index(self.gantry_dropdown.get())]) #TODO: Look into using dropdown.current instead
        except (TimeoutError,serial.SerialException) as e:
            _popup.destroy()
            print(e)
            self.popup("Gantry Connection", "Connection failed. Check that the board is connected and powered, or try a different port.", dismiss=True, sound = True)
            return
        except Exception as e:
            _popup.destroy()
            print(e)
            self.popup("Gantry Connection", "Connection failed for unknown reason. Check that everything is correctly setup.", dismiss=True, sound=True)
            return

        self.gantry_button.config(text="Calibrate Gantry", command=self.calibrate_gantry)
        self.gantry_dropdown.config(state="disabled")
        _popup.destroy()
        self.update()

    def calibrate_gantry(self):
        self.popup("Gantry Calibration", "Please make sure the gantry area is clear and press OK to continue.", dismiss=True)
        _popup = self.popup("Gantry Calibration", "Calibrating gantry_utils. Please wait...")

        try:
            gantry_utils.calibrate(self.gantry_handler)
        except TimeoutError as e:
            _popup.destroy()
            print(e)
            self.popup("Gantry Calibration", "Gantry calibration timed out. Ensure that emergency stop is not triggered.", dismiss=True, sound=True)
        except Exception as e:
            _popup.destroy()
            print(e)
            self.popup("Gantry Calibration", "Unknown error during gantry calibration.", dismiss=True, sound=True)

        self.gantry_button.config(text="Gantry Ready", state="disabled")
        _popup.destroy()
        self.update()

    #Camera
    def connect_camera(self):
        if self.camera_dropdown.get() == "":
            self.popup("Camera Connection", "No camera selected!", dismiss=True)
            return
        _popup = self.popup("Camera Initialization", "Connecting to camera. Please wait...")
        try:
            camera_utils.init_camera(self.camera_context, self.camera_dropdown.get())
        except Exception as e:
            _popup.destroy()
            print(e)
            self.popup("Camera Connection", "Connection Failed. Check that the camera is connected and powered, or try a different option.", dismiss=True)
            return
        self.camera_button.config(text="Calibrate", command=self.calibrate_camera)
        self.camera_dropdown.config(state="disabled")
        _popup.destroy()
        self.update()

    def calibrate_camera(self):
        if self.config.settings["Camera"]["Build Bias"]:
            self.popup("Camera Calibration", "Please put on the camera lens cap and press OK to continue.", dismiss=True)
        _popup = self.popup("Camera Calibration", "Calibrating camera. Please wait...")
        _popup.update()
        try:
           camera_utils.calibrate_camera(self.camera_context, adaptiveBias=self.config.settings["Camera"]["Adaptive Bias"], build_bias=self.config.settings["Camera"]["Build Bias"])
        except Exception as e:
           _popup.destroy()
           print(e)
           self.popup("Camera Calibration", "Calibration Failed. No idea why. Check terminal output and consider pulling the power.", dismiss=True, sound=True)
        self.camera_button.config(text="Camera Ready", state="disabled")
        _popup.destroy()
        #FliSdk_V2.ImageProcessing.EnableAutoClip(self.camera_context, -1, True) #TODO: Clipping type? What does it do?
        FliSdk_V2.ImageProcessing.SetColorMap(self.camera_context, -1, "NONE") #TODO: Play around with color maps
        FliSdk_V2.Start(self.camera_context)
        #self.process_preview()
        #self.display_preview(self.preview)
        self.preview.display_loop()
        self.update()

    #@threaded
    # @threaded
    # def process_preview(self):
    #     #Threaded processing script so it does not block the main(ui) thread. Uses time to not do this constantly. Might be better way.
    #     #TODO: Add stretching of the image irt. contrast. Should not be a problem now it is in a separate thread.
    #     timestamp = time.perf_counter_ns()
    #     while True:
    #         if FliSdk_V2.IsStarted(self.camera_context) and (time.perf_counter_ns() - timestamp > 10 ** 9 / self.fps): #Only run if enough time elapsed and the SDK is capturing.
    #             image = np.array(FliSdk_V2.GetProcessedImageRGBANumpyArray(self.camera_context, -1))  # -1 to get the last image in the buffer. np.array wrap to make sure it is newest version (Dont know if needed just have experienced issues before)
    #             #Any image processing goes here. Into new object, and pass that into the fromarray
    #             photo = ImageTk.PhotoImage(image=Image.fromarray(image)) #Take array, into PIL image, into image usable in tk. Have no idea if this can be improved
    #             self.preview_image = photo #Sets class variable, so it can be fetched by display_preview
    #             timestamp = time.perf_counter_ns()
    #         else:
    #             time.sleep(1E-2)

    # def display_preview(self, label):
    #     image = self.preview_image #Capture current stored image, so if it changes during it should not impact this function.
    #     label.image = image #Sets it in the label the first time
    #     label.configure(image=image) #Sets it in the label the second time. Need both lines else weird stuff happens. No clue why but I have accepted it.
    #     self.after(20, self.display_preview, label) #Run this at 50 hz ish, minus processing time or any blocking of the main thread.

    # def camera_display_loop(self):
    #     #print(FliSdk_V2.IsStarted(self.camera_context))
    #     if FliSdk_V2.IsStarted(self.camera_context):
    #         image = np.array(FliSdk_V2.GetProcessedImageRGBANumpyArray(self.camera_context, -1)) #-1 to get the last image in the buffer
    #         img = Image.fromarray(image, mode="RGBA")
    #         photo = ImageTk.PhotoImage(image=img)
    #         self.preview.image = photo
    #         self.preview.configure(image=photo)
    #         self.preview.update()
    #     self.after(20, self.camera_display_loop)

    def select_directory(self):
        dir_path = filedialog.askdirectory()
        #print(f"Selected directory: {dir_path}")
        self.save_dir_text.set(dir_path)
        self.update()

    def scan_module(self): #TODO: Implement this using the variables present in the UI
        self.popup("Scanning",
                   """Verify that:
                       -Camera cover is off
                       -Lightbar is on
                       -Scanner area is clear
                   Scanning will proceed when \"OK\" is pressed.""",
                   dismiss=True, sound=True)
        self.scan_module_button.config(text="Scanning...", state="disabled")
        for child in self.save_dir_frm.winfo_children():
            child.configure(state="disabled")
        self.update()
        #Might need to stop and start after here
        camera_utils.fetch_config(self.camera_context)
        print(self.fps, self.tint, self.gain)
        camera_utils.config_camera(self.camera_context, self.fps, self.tint, gain = self.gain)
        camera_utils.fetch_config(self.camera_context)
        buffer_size_images = int(2*self.fps*self.gantry_length/(self.gantry_speed/60))
        print(f"Buffer size images: {buffer_size_images}")
        FliSdk_V2.SetBufferSizeInImages(self.camera_context, buffer_size_images)
        #FliSdk_V2.SetBufferSize(self.camera_context, buffer_size_images)
        print(f"Context buffer size: {FliSdk_V2.GetImagesCapacity(self.camera_context)}")
        #gantry_utils.scan_continuous(self.gantry_handler,self.camera_context,self.save_dir_text.get(),self.fps,self.gantry_speed)
        t = threading.Thread(target=self.scan_thread, daemon=True)
        t.start()

    def scan_thread(self):
        linescan.continuous(self.gantry_handler, self.camera_context, self.save_dir_text.get(), self.fps,
                            self.gantry_speed)
        self.after(0, self.scan_module_button.config, "Scanned")
        # self.scan_module_button.config(text="Reset\nGantry", state="enabled", command=self.reset)
        self.after(0, self.popup, "Scanning", "Scan completed. Turn off lighbar.", True, True)

    """ def reset(self):
        self.scan_module_button.config(text="Resetting...", state="disabled")
        self.update()
        self.gantry_handler """
        

def main():
    root = tk.Tk()
    LIPI_Scanner_App(root).pack(fill="both", expand=True)
    root.mainloop()

if __name__ == "__main__":
    main()

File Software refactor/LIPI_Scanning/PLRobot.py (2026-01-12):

import os
import sys
sys.path.append('FLI_API')
sys.path.append('Stitching')
sys.path.append('Acquisition')
sys.path.append('lib')
from lib import ProcessInGaAs
from lib import imageAcquisition
from lib import gCodeHandler
from lib import stitchImages
import cv2

import datetime
import FLI_API
import tifffile
from FLI_API import FliSdk_V2


cwd = os.getcwd() #current working directory

def calibrateLoad(calpath):
    width, height = 640, 512  # Example dimensions, adjust as necessary
    K,P,DIM=ProcessInGaAs.loadCal(calpath,width,height)
    return K,P,DIM

def calibrateCamera(frameRate, tintVal, adaptiveBias=False):
    # Initialize camera
    context = FliSdk_V2.Init()
    imageAcquisition.initCamera(context, frameRate, tintVal)

    # Set bad pixel correction
    imageAcquisition.PixelCorrect(context, True)

    # Buidling bias correction. Choose between NUC calibrated bias and FLI's adaptive bias (only C-RED3?)
    imageAcquisition.BuildNUCBias(context)
    if adaptiveBias == True:
        imageAcquisition.EnableAdaptBias(context)
    #TODO: Flat correction. Fixing non-uniformity response of pixels [OPTIONAL]
    #https://andor.oxinst.com/learning/view/article/how-to-use-the-hdr-mode
    # val=input("Do flat correction?[y/n]")
    # if val=="y":

    #Enable anti-blooming
    FliSdk_V2.FliCredThree.EnableAntiBlooming(context, True)
    print("Anti-blooming enabled")
    #Enable auto clip. Only after starting acquisition?????
    FliSdk_V2.ImageProcessing.EnableAutoClip(context, -1, True)
    print("Auto clip enabled")
    # Debugging display
    return context
def calibrateGantry(gcode_handler):
    """
    Calibration method for parallel X Y gantry. First, check if end stops are functional, even if they are triggered. Then, home the gantry.
    """
    #First make sure no end stops are triggered:
    try:
        endStop= ["M120", #enable end stops
            "M119", #Check end stop status
        ]
        t=gcode_handler.send_gcode(endStop)
        axis_trig = []
        count = 0  # count for error. Do not loop forever, max two times for each axis
        while any("TRIGGERED" in line for line in t) and count < 2:
            #Check end stops
            axis_trig = []
            for line in t:
                    if "TRIGGERED" in line:
                        axis = line.split("_")[0]  # Get the axis letter (X, Y, Z, etc.)
                        axis_trig.append(axis)
            print(f"End stop for axis(es) {', '.join(axis_trig)} is triggered. Attempting to move away.")
            if axis == 'x' or axis == 'x2':
                gcode_handler.send_gcode("G0 X30")
                gcode_handler.wait()
            elif axis == 'y' or axis == 'y2':
                gcode_handler.send_gcode("G0 Y30")
                gcode_handler.wait()
            else:
                raise ValueError(f"Unknown axis {axis} in end stop status.")
            t = gcode_handler.send_gcode("M119")
            count += 1
                # if "TRIGGERED" in t:
                #     raise RuntimeError(f"End stop for axis {axis} is still triggered after moving.")
    except:
        print("Error checking end stops")
        sys.exit()
    
    gcode_handler.auto_home()
    gcode_handler.wait()
    print("Gantry homed!")
def connectGantry():
    """
    Connects to the gantry by selecting an available port and initializing the GCodeHandler.
    This function lists all available ports, prompts the user to select one, and attempts to 
    establish a connection to the gantry using the selected port. If the connection is successful, 
    it returns an instance of GCodeHandler. If the connection fails, it prints an error message 
    and exits the program.
    Returns:
        gCodeHandler: An instance of the GCodeHandler class if the connection is successful.
    Raises:
        SystemExit: If there is an error connecting to the gantry.
    """

    available_ports = gCodeHandler.get_available_ports()
    print("Available ports:")
    #choose between available ports
    for i in range(len(available_ports)): print("port {}: {}".format(i, available_ports[i]))
    t=input("choose port: (typically shows board as USB serial device)")
    port=available_ports[int(t)].device
    print(port)
    try:
        gcode_handler = gCodeHandler.GCodeHandler(port)
        gcode_handler.connect()
    
    except:
        print("Error connecting to gantry")
        sys.exit()
    return gcode_handler
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

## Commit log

2026-01-08 Belt drive+GUI redesign
    New belt drive files and some GUI experimentation
    [HGW20CA1R78Z0C-HiwinCorporation-3D-11-12-2024.stp, HGW20CC1R200Z0H_ZW_FILE_1.stp, Redesign belt drive.SLDASM]
2026-01-08 Mech Redesign
    New belt drive concept
    [NEMA23 - NEMA.step, Redesign belt drive.SLDASM]
2026-01-12 Corrected commit of refactor files and simple interface for UI
    Fixed issue with the initial commit of the refactor files (I had forgotten to remove the .git folder from the individual previous projects) and started on touch screen suitable interface. Currently an initial example is made, but code not rewriting to work with it.
    [PLRobot.py, core.py, gCodeHandler.py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]
2026-01-12 Bug Fixes
    Attempt at fixing error when connecting gantry, plus small ui changes
    [core.py, main.py]
2026-01-12 Further fixes to UI
    Trying to bugfix gantry connection
    [PLRobot.py, core.py, main.py]
2026-01-12 Fixed Gantry Connection
    Sucessfully fixed gantry connection
    [main.py]
2026-01-15 GUI with working camera
    Tested camera connection and it functions. Gantry functionality should be untouched, meaning hardware connectivity should be good. Full scan needs to be tested.
2026-01-19 Mechanical update
    Mechanical files for new belt drive polished and added
    [27 T5 _ 14-2.stp, 608Bearing - Part 1.step, MountingPlate^Redesign belt drive - 27 T5 _ 14-2.stp-1.STL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]
2026-01-19 Mech update
    small update
    [Redesign belt drive.SLDASM]
2026-01-22 UI Updates
    Added camera preview functionality to UI.
    Also internal updates in how the UI is handled, as well as beginning steps of config files and logging functionality.
2026-01-23 Belt drive redesign
    More redesigning
    [Configuration.h, MountingPlate^Redesign belt drive.SLDPRT, Redesign belt drive.SLDASM]
2026-01-23 UI Updates
    Integrated camera preview
    [ClampNoEndstop.3MF, ClampNoEndstop.SLDPRT, ClampNoEndstop.STL]
2026-01-23 Temporary fix
    Commit for testing functionality
    [core.py, main.py]
2026-01-28 Belt discs
    [Belt stabilizer disc.SLDPRT, MountingPlate^Redesign belt drive.SLDPRT, Redesign belt drive.SLDASM]
2026-01-28 Threaded Preview
    Minor updates to UI and attempted threading of Camera Preview
    [ClampNoEndstop.SLDPRT, ClampNoEndstopV2.STL]
2026-01-29 UI Polishing
    Bug fixes on preview and error correction
    [PLRobot.py, core.py, gCodeHandler.py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]
2026-01-29 Test
    Testing to fix some error when building bias
    [core.py, gCodeHandler.py, main.py]
2026-01-30 Cleaning pycaches
    Getting rid of annoying files from compilation. Was tired of them getting tracked.
2026-02-01 FliSdk removal
    Hopefully fixes any issue with the FliSdk by completely removing it as a part of the project, and in the main script adding the python interface directly to the path, similar to what was previously done, but using same method as the Sdks LibLoader to automatically find the file path on the PC. From what I could test at home it worked. Might be more robust, wanted to try it. Easy to undo, and want to do it similarly anyways to not have to ever edit the files.
    [core.py, main.py]
2026-02-01 Small UI updates
    Added popups when starting scan and after scan. Dropdowns to select devices are now disabled after connecting. gcodehandler now sends gcode M115 on connection and prints response. Eventually this sho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
2026-02-02 .tiff save format
    and fix separation algorithm
    [manualStitch.py]
2026-02-03 Endstop design and high FPS scanning update
    [Belt stabilizer disc.SLDPRT, ClampEndstop.SLDPRT, ClampNoEndstop.SLDPRT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]
2026-02-03 Fixed FLI_SDK import in LIPI_Scanning main
    [main.py]
2026-02-03 Buffer reset before capturing scan
    Resets buffer before starting the scan
    [main.py]
2026-02-03 Fix x-speed and nimage calculation
    [core.py]
2026-02-05 UI Updates and bugfix
    Updates including testing a new function to do the scan. Bugfix by not running detect cameras constantly.
    [core.py, main.py]
2026-02-12 Threading and config beginnings
    Additional notes and updates text on some boxes. Added a new decorator for functions "@threaded", which makes it run in a thread in place without having to start a thread in the function. Also makes 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
2026-02-12 Undid config change
    Made a change to test some config stuff, but replaced some class variables in the process. Added those back so it should work while changes are happening in the background.
    [main.py]
2026-02-25 Config Window Introduced
    Simple implementation of a config window including full save and load functionality introduced. Right now it does not do anything, as the main program needs to be changed to use the config settings. 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
2026-02-26 Added lightbar config and first attempt at updating values from config
    Small changes to the config implementation, also including a precision option. Where this is called should be changed in the future (along with callback method) to allow simpler repeated writing, and allowing to skip it entirely for a default value.
    [main.py]
2026-02-26 New Offset + bed size
    X=2200mm
    Y=2100mm
    [Configuration.h]
2026-02-26 Variable update in stitching and debug added to scanner
    Updated variables in stitching to match current configuration. Also debug code to scanning because there is a weird drift in the splitting.
    [StitchApp.py, core.py, main.py]
2026-03-03 Initial analysis for dealing with camera
    Some initial analysis for making a working modulated stitch with the camera issues, including some nice discoveries along the way, like potentially an automatic way to detect the module boundaries pre stitching.
2026-03-07 POC for DSP based stitch
    Stitched image achived in testing_fps_wrong for stitching an image using a digital signal processing approach. Issues with contrast, and that updated parameters for dpf_px need to be found. Of course need to see what happens when more noise is introduced.
    [manualStitch.py]
2026-03-12 3D design update and stitching UI bug fix
    [Belt stabilizer disc.SLDPRT, ClampEndstop.SLDPRT, Extrusion1^Redesign belt drive.SLDPRT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]
2026-04-16 Changes to processing and scanning
    Processing:
    Highlights: Updates to enable processing of outdoors scans
    ingaas_processing: Updated raw image load to be able to handle only loading partial data, as to in some cases avoid overloading ram.
    testing_fps_wrong: Continued work on stitching algorithms, especially for outdoors use. Implemented partial image use, to avoid using too much memory and cut out noisy parts of image. Needs to be moved to proper package.
    Scanning:
    Highlights: Added two config options "Build bias" and "Adaptive bias", previously only controllable from the code. Also disabled autoclip, and adjusted exposure so that it can take float values.
    main: Fullscreens on launch aga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
    [core.py, main.py]
2026-05-05 Cred3 class iteration 1
    First complete version of wrapper class for the Cred, which I hope will improve stability by being simpler to work with / setting any weird corrections that need to be done in stone. Still some things that probably are not best practice, but at least it is all in one place now.
    [main_v2.py]
2026-05-21 More mechanical stuff
    Wheel mounts more robust, new lens expanders
    [Lens_Expander - NikonLensExpander.sldprt, MountingPlate.STEP, WheelMount.SLDASM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]
2026-06-01 First pass of new class objects, and CLI interface utilizing them
    UNTESTED. Updated class for CRED3 camera. Wrapper class introduced for gantry, bundling some helper functions that where previously separate. Finally scanner class introduced, to internally keep trac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
2026-06-10 Clamps
    Added cable clamps
    [CableClip^Redesign belt drive.SLDPRT]
2026-06-12 Small modifications
    Comments for most obscure parts of the code, as well as a GetStatus call to the FliSdk in cred3.start to try and ensure the camera is actually started before continuing the code.
2026-06-12 Added auto expose and gantry auto connect
    First version of gantry auto connect and camera auto expose added to main_CLI. Both are currently optional in the run script as they are early versions. If they work well, they will be default in the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
2026-06-17 Prelim SNR calculations
    [CableClipTopDown^Redesign belt drive - Copy.SLDPRT, CableClip^Redesign belt drive.SLDPRT, Redesign belt drive.SLDASM]
2026-06-18 Auto expose bug fix
    [main_CLI.py]
2026-07-07 Processor script for LIPI results
    First version of processor script capable of taking a folder outputted by scanner and processing it, splitting it into images. Contains two version of a SNR calculation. Some errors in how this are done, including that the outputted images are saved in a seemingly weird format, meaning you cannot load them back in for future use, but have to run the whole processing of the raw file again.
    [main_CLI.py, reprocessor.py]
2026-07-16 Improvements to scanning
    Now does gantry auto connect as standard
    Split scan function in scanner into setup and scan. This allows slow buffer setting and movement to offset to be done before a scan catch statement, meaning the scanner will start scanning faster aft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
    Improvement of "safety" of the cred3 frame function, as to now ensure that the camera is functioning. Can be overridden by setting debug to true.
2026-08-07 Large changes and experiments regarding callback functionality
    Work on developing livestitching. Several attempt are here, some developed using ai assistance, though those attempt are middling in their success. Bug solved in cred3 class.
    [auto_exposure.py, callback_testing.py, continuous_stitch.py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]
2026-08-12 Hopefully fixed auto exposure
    Updated auto exposure, now using established numerical analysis methods. Untested currently. Potentially issues with how SciPy functions and device communication but we will have to see. Else, manually writing the method is a possibility, but is just a chore.
    [auto_exposure.py]
2026-09-10 Many updates
    Such wow. A bit too long since i committed i think, my bad...
    [auto_exposure.py, livestitch_v2.py, main_CLI.py]
2026-09-20 Updates to get extrema code, and testing on translation for individual frames

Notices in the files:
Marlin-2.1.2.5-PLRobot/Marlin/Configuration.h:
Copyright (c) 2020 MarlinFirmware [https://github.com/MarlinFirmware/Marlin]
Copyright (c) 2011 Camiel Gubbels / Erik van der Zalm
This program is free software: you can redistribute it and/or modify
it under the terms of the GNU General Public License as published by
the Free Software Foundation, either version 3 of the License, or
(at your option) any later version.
